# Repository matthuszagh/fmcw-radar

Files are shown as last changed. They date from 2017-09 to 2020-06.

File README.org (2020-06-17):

This repo has been moved to [[https://github.com/matthuszagh/fmcw][fmcw]] to support git-lfs (public forks do not support LFS).

* About
:PROPERTIES:
:ID:       20ff1c28-cfc6-4280-8501-83314fee390d
:END:
This repo includes the custom PCBs and PC control software necessary
to build and operate a 6GHz FMCW radar. It also includes a number of
other useful additions, such as RF and SPICE simulations (in progress)
as well as CAD designs for the horn antennas and PCB cases.

The project is a fork of [[https://github.com/Ttl/fmcw3][Henrik's excellent design]]. Although I've made
a number of [[id:8f78da8c-ec0c-40f3-9b8b-6c1af11f4bb2][significant changes]], most of the main PCB (as of this
writing) is still identical to Henrik's. Despite the fact that Henrik
deserves a large share of the credit for this project, he is in no way
affiliated with this fork.

This project is still in its early stages. In particular, there are a
number of hardware issues that make this version inferior to
Henrik's. These will be fixed in a future version, but I would hold
off building this version until these issues are fixed.

* TODO Capabilites
Briefly mention the radar's capabilities.

* TODO Installation
* TODO Additional hardware
* Modifications from the original
:PROPERTIES:
:ID:       8f78da8c-ec0c-40f3-9b8b-6c1af11f4bb2
:END:
The FPGA code has been completely rewritten and expanded so that
nearly all data processing is now done on the FPGA. This was done
while keeping the same FPGA chip. This allows the fully processed
output to be plotted in realtime and simplifies the data processing
requirements of the host PC code. The FPGA code also includes
automated tests and, in some cases, formal verification.

Because the FPGA responsibilities were expanded, the PC software had
new requirements and had to be rewritten as well. The software is
multithreaded and separates out the task of acquiring data from
plotting it. Additionally, the software and FPGA gateware have been
designed to make the radar easier to debug. For instance, data
processing can be shared in any way between the software and FPGA,
which makes gateware bugs easier to isolate. It's also possible to
request data from the FPGA in any intermediate form.

I completely redid the PCB layout because of the need for a new power
amplifier (note that this introduced at least [[id:0246fbe1-ba4a-4bf6-b551-a896264dea3a][one significant issue]]).

I've added horn antennas that can be built by anyone with access to a
3D printer. There's also a 3D-printable mount to hold the entire
structure.

I've greatly expanded the documentation, which should be useful to
anyone who wants to understand how the radar works in detail.

I've added a number of RF simulations (using [[https://openems.de/start/][OpenEMS]]) and spice
simulations (using [[http://ngspice.sourceforge.net/][Ngspice]]).

Finally, I have plans to multiplex 8 receiver antennas across the 2
receiver channels for better angular resolution. The PCB has already
been built (though is untested), but I haven't yet had the time to
write the FPGA code and software to support it.

* Issues and To-Do
:PROPERTIES:
:ID:       0246fbe1-ba4a-4bf6-b551-a896264dea3a
:END:
The power circuitry that was added to accommodate a new power
amplifier (the original was deprecated) adds noise that shows up in
the final output. Because of this problem, if you're able to track
down the old power amplifier I'd recommend using Henrik's design
instead. My FPGA code and software (at least for now) should be fully
compatible with the original hardware. I intend to fix this problem in
a future version.

I'm currently working on a number of RF simulations that will
eventually lead to a replacement of some of the RF PCB
layout. Currently, I have very limited information on whether these
parts of the PCB actually work the way they should. Areas of focus
include transmission line characteristic impedance, transmission line
to SMA transitions, and replacement of discrete components such as
couplers, attenuators, etc. with the equivalent components etched
directly onto the PCB. Once the RF simulations are complete, I'd like
to prototype these before actually building them into the
radar. Unfortunately, I don't yet have the proper testing equipment
for this (building a VNA is the next project...).

* Contributing
Pull requests and issues welcome. I'm open to suggestions for hardware
modification, although may or may not be able to merge those commits
depending on whether I can test the change.

* TODO Operation
Link blog post.

* TODO Attribution
+ Henrik, of course (see [[id:20ff1c28-cfc6-4280-8501-83314fee390d][About]]).
+ An additional thanks to AlexBdx for finding a way to 3D print horn
  antennas.

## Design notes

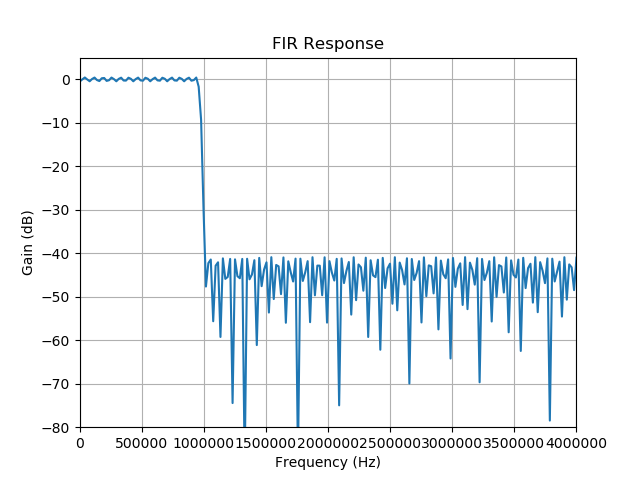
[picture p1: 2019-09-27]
fpga/fir/plot_response.png

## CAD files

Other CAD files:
hardware/cad/antenna-mount.scad
hardware/cad/horn-antenna.scad

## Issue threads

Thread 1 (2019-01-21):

USB type C

matthuszagh, 2019-01-21:
I'd like to use a USB type C connector in place of the current micro B USB 2.0 connection. The plugs/receptacles are symmetrical, support higher speeds (if the interface/FPGA will allow it) and are the future, so it would be nice to gain experience with them. The interface controller will need to be changed, since the FT2232H does not support USB standards past 2.0.

Ideally, I could use this to power the board. However, that would require at least 1 boost converter (an amplifier in the transmitter requires a 10V power supply) and might be a bit tight on current. USB C should allow up to 3A of current at 5V, which would be theoretically sufficient, but it doesn't leave a lot of leeway.

Closed 2020-06-03.

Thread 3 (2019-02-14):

Fix FT2232H EEPROM

matthuszagh, 2019-02-14:
Change 93LC46BT-I/SN to 93LC46BT-I/OT and add 10k pull-up resistors to EECLK and EECS (pull up to 3.3D).

Closed 2020-05-19.

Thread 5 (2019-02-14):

Change pushbutton switch type

matthuszagh, 2019-02-14:
Exchange the current switch (EVP-AWBD2A) with the one used in the icebreaker board (PTS810 SJM 250 SMTR LFS) which is a much better size and is generally nicer.

Closed 2020-01-03.

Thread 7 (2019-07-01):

Patch antenna

AlexBdx, 2019-07-01:
Hello,

Is this patch antenna the one that Henrik used or your own design based on his post?

matthuszagh, 2019-07-02:
It's basically Henrik's. He gave me the gerbers for an array of 2 but I turned it into a single patch and imported it into kicad (the one patch should be identical to his though). If you're interested in the original gerbers I can give those to you. I'll be turning this into an 8-array antenna (multiplexed through 2 rec channels) and running sims in openems, just fyi if you're interested. Not sure the eta on that

AlexBdx, 2019-07-02:
Yeah I saw your multiplexing board. I have ordered a copy of your array of 2 after talking with Henrik. What connectors did you use? I saw a footprint with 9 holes and was wondering of you had a reference for it.

matthuszagh, 2019-07-02:
Hm 9 holes.. Are you talking about the RF via (reference F1 and F2)? That one only has 6 holes though. If you provide me more info or a screenshot or something I can tell you what it is. For sma cables I'm using [these](https://www.amazon.com/gp/product/B072FS4WMK/ref=ppx_yo_dt_b_search_asin_title?ie=UTF8&psc=1). They work fine. you'll need a transmission antenna too. have you sorted that yet? I'm currently using [this one](https://www.amazon.com/gp/product/B07D28MW63/ref=ppx_yo_dt_b_search_asin_title?ie=UTF8&psc=1) planning to probably build my own later. If you want something cheap the one from the link is good. Unfortunately you lose half the transmission energy because the tx/rx polarizations don't match, but as a first pass to get the board working it's good

AlexBdx, 2019-07-02:
Yep I got that Tx. I saw that in your doc and that will be perfect for a first run (I saw a single feed version mentioned on Martin's website but could not find anyone that sold it).
Regarding the RX, I imported your files from the antenna folder and basically sent that straight to PCB manufacturing. In Kicad, everything appears as a via to me. Below is a the file I am using. Let me know if you can see it.
[Patch_2x5.zip](https://github.com/matthuszagh/fmcw-radar/files/3352443/Patch_2x5.zip)

matthuszagh, 2019-07-02:
ah i see why you're confused. that kicad_pcb file is wrong. fortunately the gerbers in the antenna directory look fine. in any event this is the [surface sma i used](https://www.digikey.com/product-detail/en/linx-technologies-inc/CONSMA001-SMD-G/CONSMA001-SMD-G-ND/4496569). That's all you need, plus the sma connector cables. i'm gonna try to track down the right kicad_pcb file but might not get to it right away.

AlexBdx, 2019-07-02:
Damn! I just uploaded all the files in Gerber (through KiCad) and then Saved As a kicad_pcb file. Did I have to make some modifications beforehand? I just got an email saying that the PCB had gone to the fabricator, but maybe I can cancel the order if the board cannot be easily modified. Let me know!
I'll order the SMA connector you mentioned so at least I have these ready.

matthuszagh, 2019-07-02:
Ah sorry about that! Yeah I'd try to cancel if you can, I think there's a good chance it won't work properly. To clarify, the exposed copper looks like a bunch of overlapping circles?

matthuszagh, 2019-07-02:
For reference the correct gerber looks like this
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

AlexBdx, 2019-07-03:
Okay, can you send me the correct files you have? Or maybe update the repo? It might be easier to swap the gerber files at the fabricator than outright cancel as my order is grouped with dozens of others on a panel.

matthuszagh, 2019-07-03:
The gerbers in the repo are right but it looks like kicad doesn't know how to convert it to a kicad_pcb file. I just tried the conversion here. does the mfg allow you to just send gerbers? i'd just use those directly

AlexBdx, 2019-07-03:
Wow yes indeed! I tried to upload the gerber zip that you have in the antenna folder and it looks much better. The attached shape is correct right?
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

matthuszagh, 2019-07-03:
Looks good!

AlexBdx, 2019-07-11:
Hey,
I put together the antenna and wired everything, but unfortunately I'm not getting any meaningful data yet. The ADL5802 on the board gets really hot and it seems that the LOIN/LOIP pins are shorted, even if I cannot see any soldering issues on the board. Did you have troubles with this chip at all?

matthuszagh, 2019-07-12:
Not really, the only issues I encountered were a few simple shorts that we are all fixable. The trick was tracking them down.

AlexBdx, 2019-07-13:
Mmmh, I'm a little puzzled. I get some data, but it looks like crap. My channel 2 does not seem to be getting anything meaningful.
Do you have a log file you could share so I can run plot_log and see how the results should look like when it works?
I uploaded one of mine here if you are interested/have time to look at it: [https://github.com/AlexBdx/fmcw3/tree/master/pc/python2/run_away](run_away)
The log file is called run_away.log and in the img/ folder you have the plots I generated - they don't look so good. Let me know!

matthuszagh, 2019-07-19:
https://www.dropbox.com/s/luuqggbdlmfhpul/fmcw.log?dl=0

here's a log i took. you can't really see anything on the angular range plots, but the range time plot is ok. i'm hoping the antenna simulations and multiplexed antenna will yield something with better angular resolution and better snr, but not done with that yet.

I took a look at yours and it seems like you're getting repeating data.. not entirely sure what might be causing that. did you check for shorts at the receiver? I had one on one of the lna's that caused bad data. just a thought.

AlexBdx, 2019-07-19:
in read_settings, it raises a ValueError due to missing error.
if header != 'fmcw3;':
        raise ValueError('Missing header')
Did you modify fmcw3.py and discarded the header?

I have fixed "some" issues on my board (found one tricky short on a non-populated yet connected pad) but I'm done 100% done. I hope to find the others soon.

matthuszagh, 2019-07-19:
oh yeah i changed the name. you have to modify the python code to look for fmcw, not fmcw3

AlexBdx, 2019-07-20:
Do you have the corresponding plot_log.py file too?
I've tried yours & Henrik's legacy file, removing errors one after another until I would be processing the reading the whole log... only to end up with empty arrays.
Maybe you could send me the one you used so I don't have to reinvent the wheel on this one.
Have a great weekend!

matthuszagh, 2019-07-24:
https://www.dropbox.com/s/3eo8sn8id342ecr/plot_log.py?dl=0

let me know if that works

AlexBdx, 2019-07-24:
Stupid mistake on my end: I was trying to read your file with python 2 (what Henrik initially used) while I had to run it with python 3. Your range-time plot is noisy, but I can definitely see a signal on it!! Looks great!
Yes, it did work. A couple of questions:
- I thought that the IF time domain waveforms would be limited to [-1; 1] V but I see that the signal spiked outside these bounds at times. How is that happening? I thought the ADC's largest sampling range was 2V.
- The IF time domain plots have a ton of noise in your signals. Is that normal? How can the noise be reduced?
- Each channel on each sample of the IF time domain plot seems to have a mean of about -0.25 V. Why isn't it 0 V?

AlexBdx, 2019-07-29:
I forgot to add one of the pictures I had processes to illustrate my previous message. Let me know when you have a second to look at it. Thanks!

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

AlexBdx, 2019-07-31:
Wow I finally fixed it. I found a new issue after checking everything again, and now it works. Check that out:

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

matthuszagh, 2019-07-31:
glad you figured it out!

Closed 2019-07-31.

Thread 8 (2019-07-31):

Multiplexed fmcw

AlexBdx, 2019-07-31:
Time to get real, now that the board is working.
How far did you get on the multiplexing? I saw your Kicad file, did you:
- Make it?
- Write the code FPGA code to support it?
- Python/pc code for it?
I'm interested in pushing a little forward that idea, so let me know!

AlexBdx, 2019-08-30:
Regarding point 3, I've made some progress actually.
Would you mind testing my version of the fmcw3 python code and let me know if it works on your end too?
You would need to install the files I used with `pip install fmcw` and then run the attached main file. Thanks!
[rt_fmcw3.zip](https://github.com/matthuszagh/fmcw-radar/files/3558005/rt_fmcw3.zip)

matthuszagh, 2019-09-03:
I'll try to test this when I can. What's the purpose of this code? Is it to support antenna multiplexing? If so, my testing will be a bit delayed since I don't yet have the receiver antennas and haven't modified the FPGA code to support it.

One of the main goals of this project for me was to learn FPGA dev, so I've been working to get all functionality (except plotting of course) onto the FPGA. All the individual modules work and now I just need to connect them together and test it, so hopefully I'll have a complete solution (including realtime plotting and antenna multiplexing) soon. I'll post back when I do.

AlexBdx, 2019-09-03:
In a nutshell:
- Work at a higher level than Henrik's code by providing functions/classes/modules... and documenting stuff a lot more
- Add some features

Key features:
- Runs Henrik's core physics
- Display IF signals/Angle/Range time in real time. Optionally, connects to a webcam and records video of the scene imaged.
- Saves data to binary & csv (in csv mode you save the integer values of the IF signal)
- Way more robust management of the USB connection, less than 5% of the sweeps are dropped now.
- Heavy reliance on the multiprocessing library to allow regular laptop to perform okay

AlexBdx, 2019-09-03:
I know ~ nothing about FPGA, so I'm glad you are taking a stab at this challenge. Performing the FFT on the FPGA would definitely be more efficient than on a laptop. However, it's a lot harder to write than a few call to Numpy so if you go that route I would be interested to see how you did it.

matthuszagh, 2019-09-03:
Nice job getting all this working with just python code. I'm looking forward to testing it. I actually think your solution makes more sense for most applications than mine. The FPGA code is more efficient, but less flexible when you want to change something and as you mentioned harder to program. I'll be happy to walk you through it when I'm sure it actually works.

AlexBdx, 2019-09-03:
Thanks! Let me know if my script works for you. If you use windows, there might be some linux specific implementations that derail it.
Also I added my personal script to the fmcw library so you can just run YYMMDD_rt_fmcw3.py from there and see what happens. Thanks!

AlexBdx, 2019-09-14:
I've created a slack channel for the fmcw so we stop writing endless issue threads
[https://join.slack.com/t/fmcwworkspace/shared_invite/enQtNzYyNTcwNDI0MTgyLTU4NzEzMDA3NTU5ZjI2YTY3MTI5ZmQ0ZDFkOGNlNGRjMzgxNzE1NWZhYjgxZDIyNDlkM2U3YjRhY2RhMGNlOTg](url)
Feel free to join!

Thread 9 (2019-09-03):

Homemade horn antenna

AlexBdx, 2019-09-03:
I remember you previously said you wanted to make your own antenna.
I found this article: https://antennatestlab.com/3dprinting
and made my own horn antennas for the fmcw3. They cost nothing and are fun to build.

AlexBdx, 2019-09-03:
Purely informational. If you do not have a 3d printer available you can email me.

matthuszagh, 2019-09-03:
This is awesome, thank you for sharing!

matthuszagh, 2019-09-03:
I'm curious, did you build small horn antennas for reception too, or just a large one for transmission?

AlexBdx, 2019-09-03:
If I just want the range-time plot, I use two horns like Henrik does (check out his new article if you have not already).
If I want the angle plots, just for the transmission due to the need to have a specific alignment between the antennas.
That being said, you could probably design a very narrow horn, and stack them side by side with a lambda/2 pitch. The horn would be non-ideal, but it might be better than the FR4 patch \o/

matthuszagh, 2019-09-03:
Yeah I'm not in love with the patches. The bandwidth on them is terrible and FR4 is tough to work with for antennas. I'll see if I can make horns small enough for reception and report back if they work any better.

AlexBdx, 2019-09-03:
Sounds good.

matthuszagh, 2019-09-04:
you used the wr187? what did you do for waveguide coax adapters?

matthuszagh, 2019-09-04:
wr159 is a better frequency range but i don't see an stl model for it

AlexBdx, 2019-09-04:
No I made a WR-159

matthuszagh, 2019-09-04:
is the model there and i missed it or you made it yourself?

AlexBdx, 2019-09-04:
I made a CAD myself for the WR-159 and 3d printed it. I used the following drawing: https://www.pasternack.com/images/ProductPDF/PE9860-15.pdf
My 3D printer can only do 6"x6"x6" so I had to split it in 2. I did not have the motivation to split it in 4 to make a 20 dBi version

AlexBdx, 2019-09-04:
Let me see if I can 1) find the file 2) attach it on Github

AlexBdx, 2019-09-04:
>
>
> you used the wr187? what did you do for waveguide coax adapters?

2nd part of the answer: I *could* have 3D printed one, but I concluded it would be too risky. So I just bought this: https://www.ebay.com/itm/232688038314

matthuszagh, 2019-09-04:
makes sense, thanks

AlexBdx, 2019-09-04:
[WR-159_15_dBi.zip](https://github.com/matthuszagh/fmcw-radar/files/3572572/WR-159_15_dBi.zip)
Assembly_15_dBi is for reference: there are two parts due to the size constraints of my printer. Support_PLA is a conical section that holds the top and bottom parts aligned while you weld the two parts together (via solvent or glue or else)

matthuszagh, 2019-09-04:
thanks!

Closed 2019-09-03.

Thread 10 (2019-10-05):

Power amplifier is turned on when power is supplied

matthuszagh, 2019-10-05:
The power amplifier is enabled with a low voltage. Perhaps this should
be inverted.

matthuszagh, 2020-06-03:
This isn't a problem. Since the FPGA IO pins are high-Z before configuration, the PA will be disabled by default. However, since the FPGA is configured to read its bitstream (master SPI) from the onboard eeprom (w25q32), ensure this doesn't set the pa_en_n_o pin to 0, in which case the PA will be on soon after power is supplied.

Closed 2020-06-03.

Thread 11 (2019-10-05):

ADC references are not connected to 3V power rails

matthuszagh, 2019-10-05:

matthuszagh, 2020-01-03:
Fixed: https://github.com/matthuszagh/fmcw-radar/commit/e4269df8504eb95caaa8f14ce68d8890eff62e64

Closed 2020-01-03.

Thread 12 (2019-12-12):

500KHz tone in output

matthuszagh, 2019-12-12:
I think this is coming from the power supply (the upstream switching
converter switches at 500KHz).

The first step is to measure the power supply noise and determine if
that is indeed the source of the noise. If so, the contents below
apply. If not, I don't yet have an alternate theory.

The tone comes from the TPS5420D switching converter. The problem
is some combination of the following:

1. TPS5420D produces too much ripple. Could use the old L7980 instead.
2. TPS7A7001 linear regulator (downstream) has inadequate PSRR. In
   this case, it should be replaced with the old TPS7A91 (we'll need
   2, 1 for the mixer and another for the power amp, in order to meet
   max current draw).

Possible solutions (some combination of these):

1. Revert to L7980 and TPS7A91. Have mixer and power amp use separate
   TPS7A91 to accommodate current draw.
2. Use a capacitance multiplier (see the art of electronics section
   8.15.1) between the converter and regulator.

matthuszagh, 2020-06-03:
New design reverts to L7980.

Closed 2020-06-03.

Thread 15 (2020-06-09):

FPGA mode pins should be switchable

matthuszagh, 2020-06-09:
Should use a switch on the FPGA backside to allow the mode pins to be set without soldering/desoldering resistors. This is useful, for instance, if you don't want the FPGA to be automatically configured from SPI flash at startup.

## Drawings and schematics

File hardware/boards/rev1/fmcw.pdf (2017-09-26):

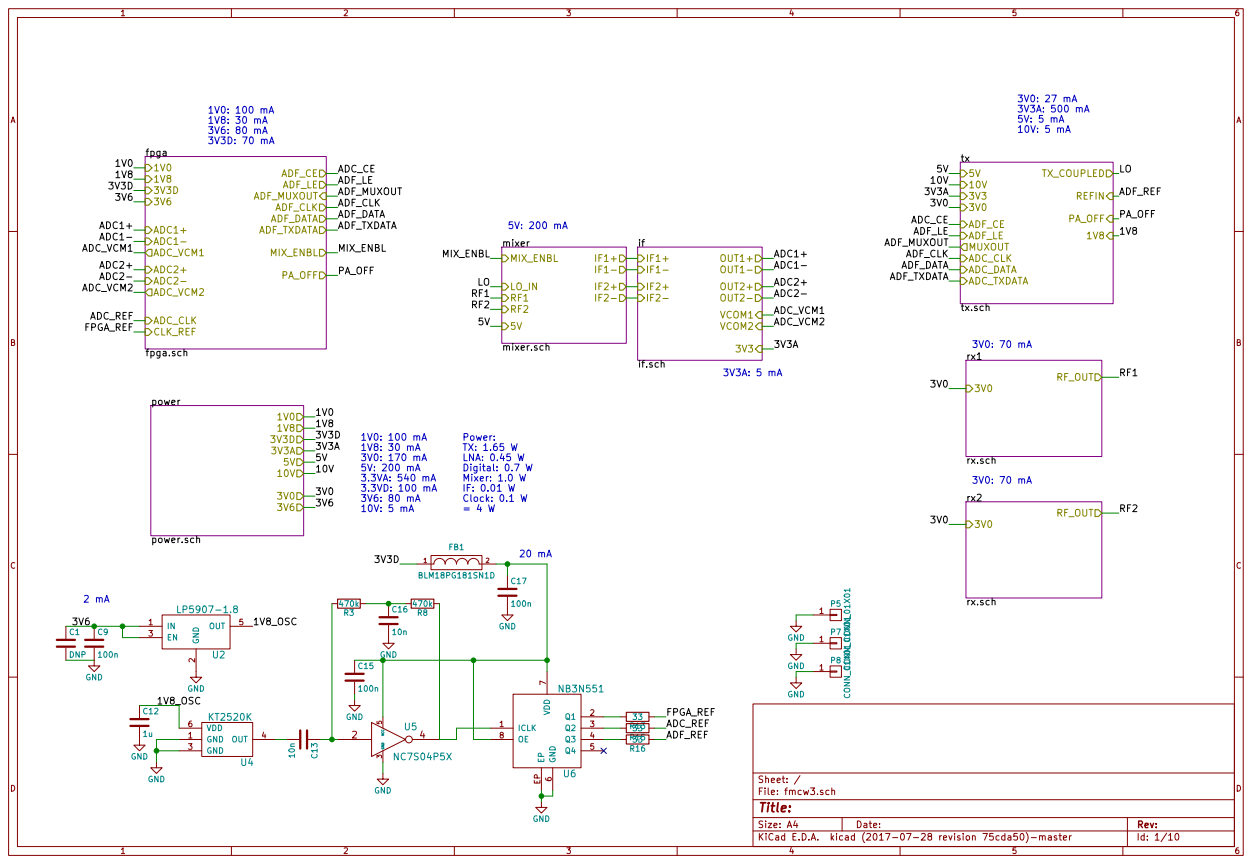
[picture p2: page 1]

Id: 1/10 Title: File: fmcw3.sch Sheet: /

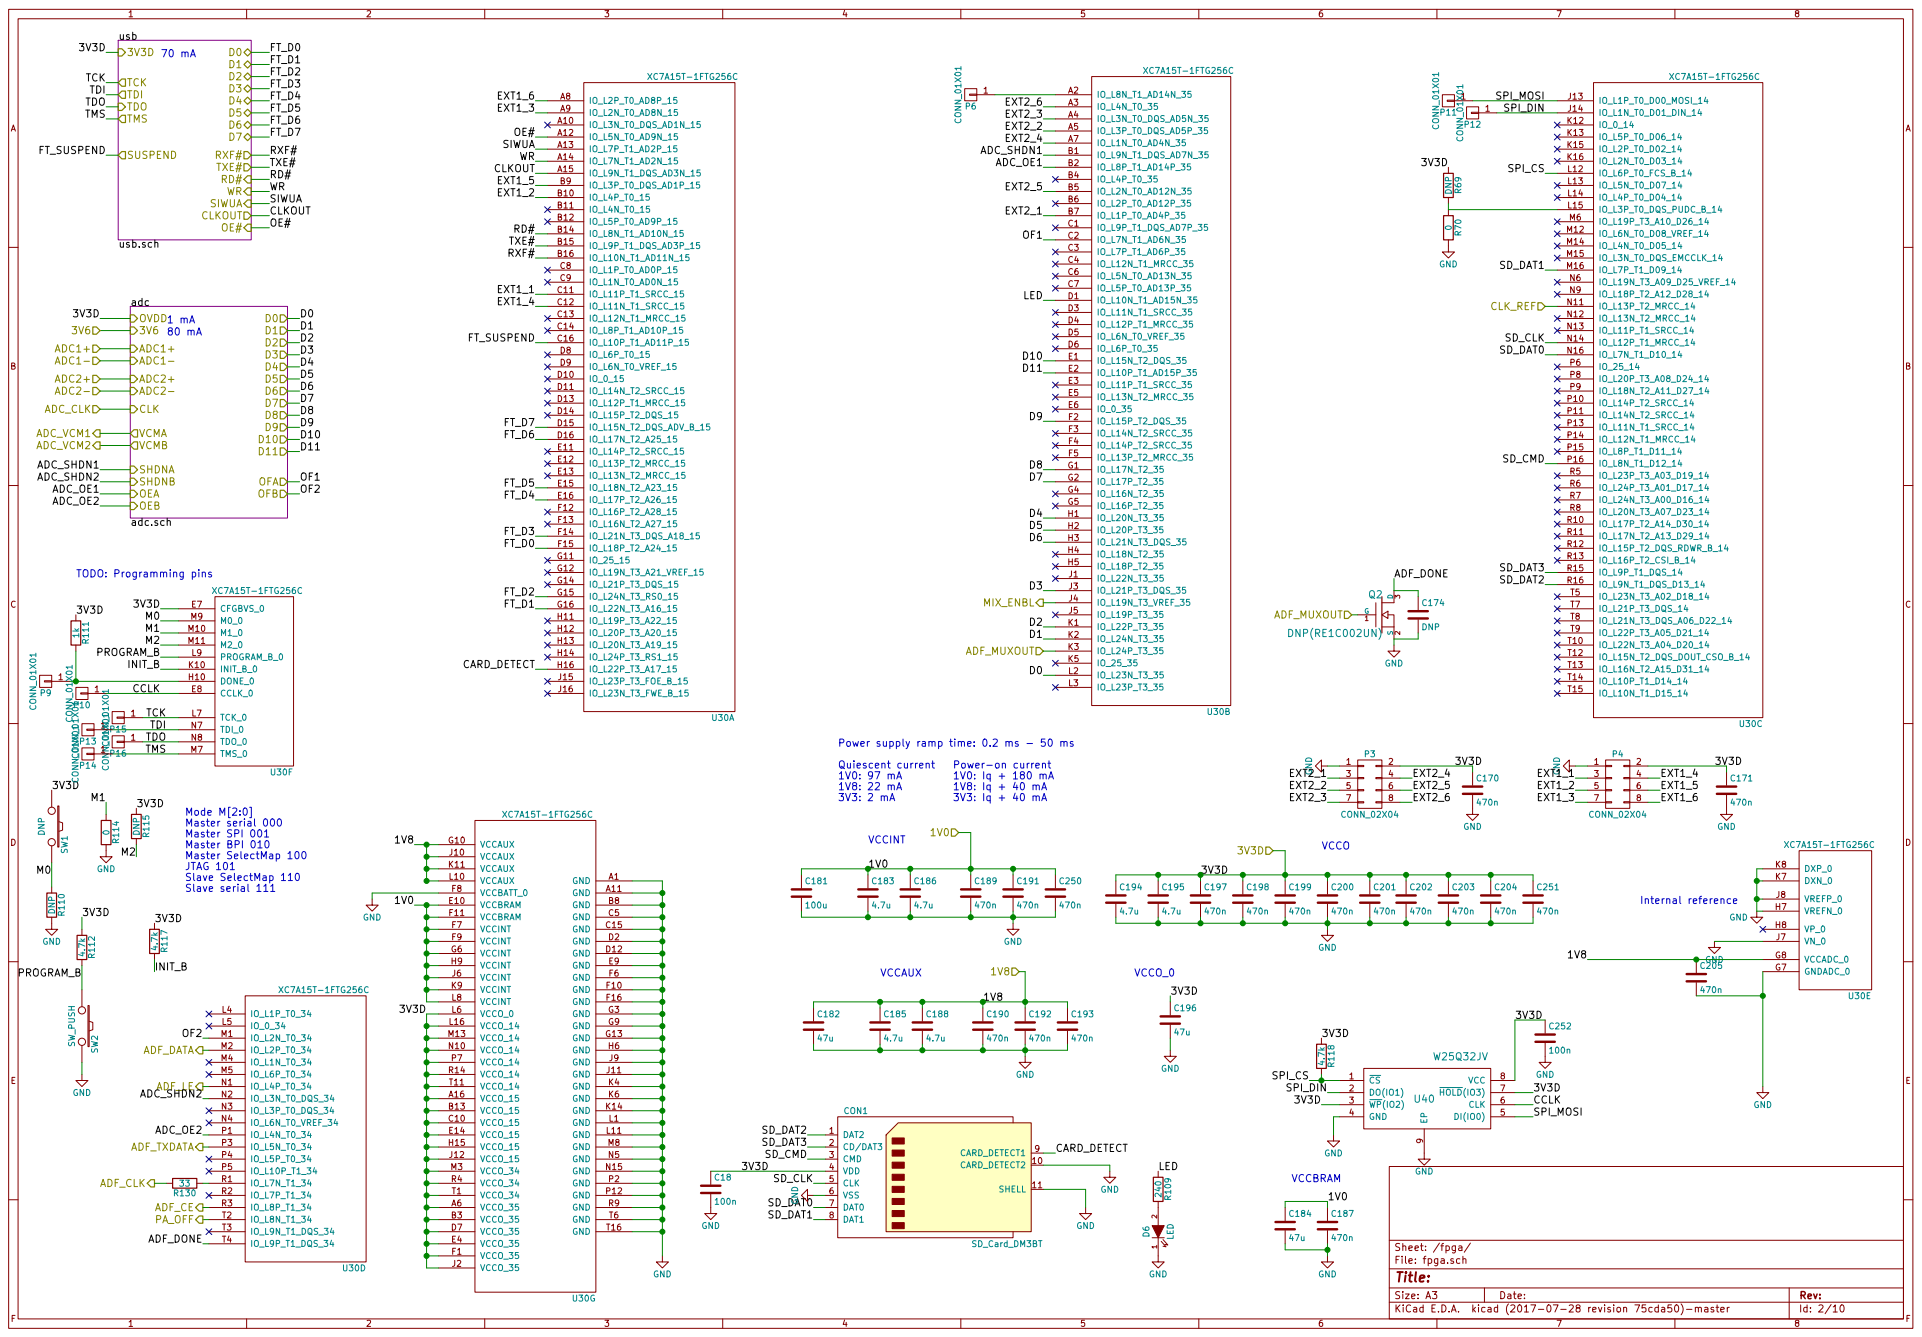
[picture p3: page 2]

SIWUA CLKOUT OE# SUSPEND

Power supply ramp time: 0.2 ms - 50 ms
Internal reference Quiescent current 1V0: 97 mA

Power-on current 1V0: Iq + 180 mA

Id: 2/10 Title: File: fpga.sch Sheet: /fpga/

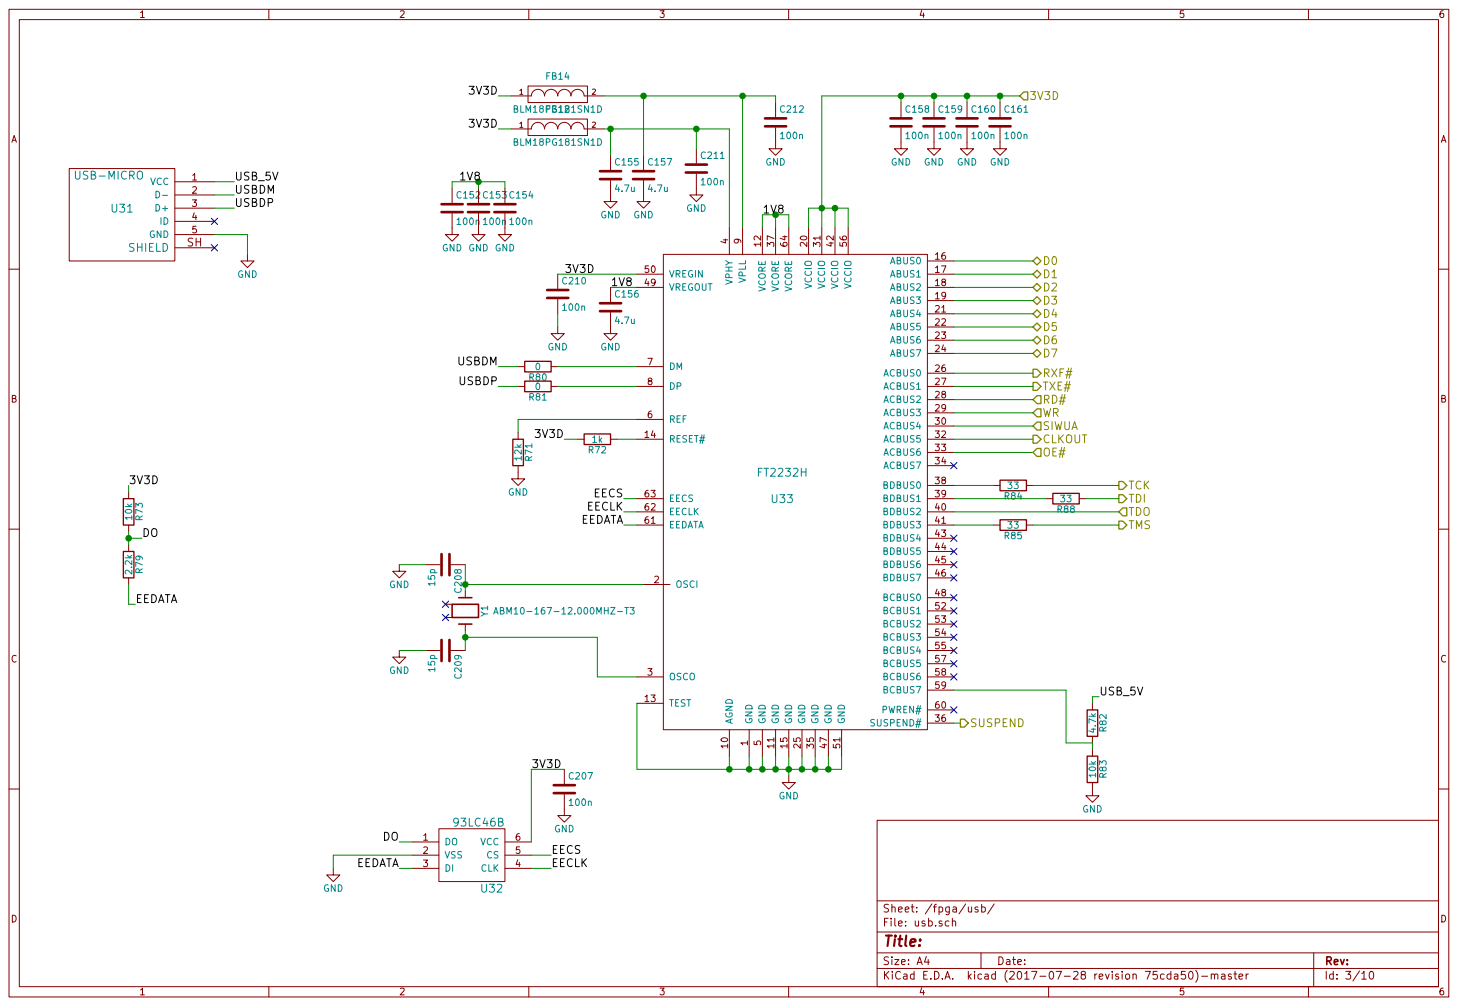
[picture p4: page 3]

Id: 3/10 Title: File: usb.sch Sheet: /fpga/usb/

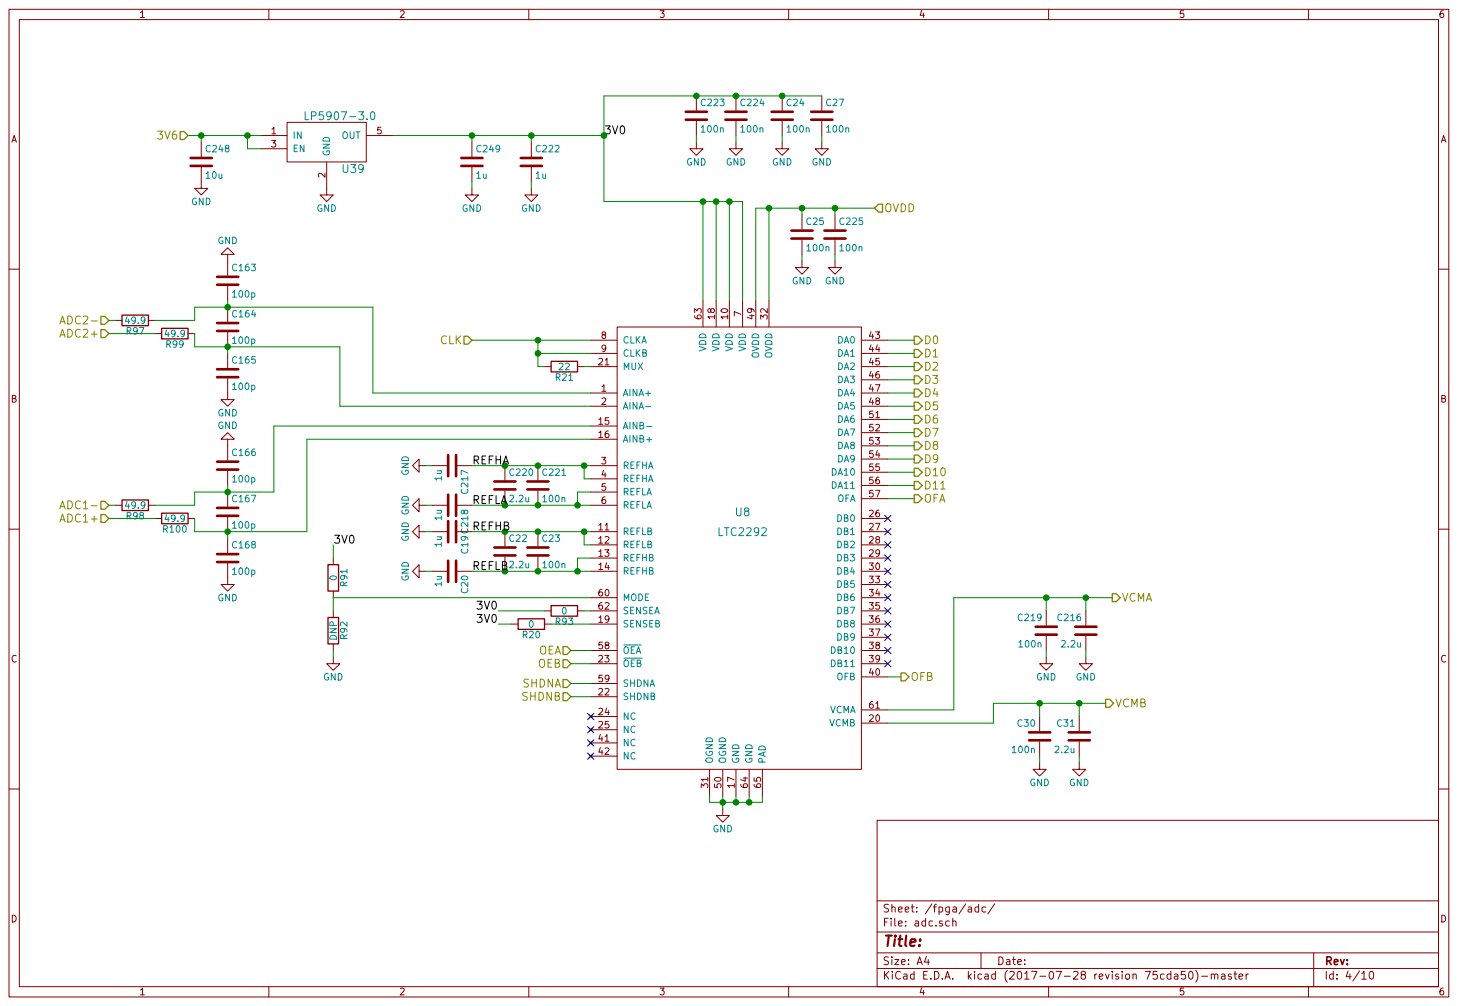
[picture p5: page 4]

7 CLKA 8 CLKB 9 VDD 10 VCMB 20 DB4 30 OFB 40 OGND 50 MODE 60 REFLB 11 MUX 21 OGND 31 NC 41 DA6 51 VCMA 61 REFLB 12 SHDNB 22 OVDD 32 NC 42 DA7 52 SENSEA 62 REFHB 13 OEB 23 DB5 33 DA0 43 DA8 53 VDD 63 REFHB 14 NC 24 DB6 34 DA1 44 DA9 54 GND 64 AINB- 15 NC 25 DB7 35 DA2 45 DA10 55 PAD 65 AINB+ 16 DB0 26 DB8 36 DA3 46 DA11 56 GND 17 DB1 27 DB9 37 DA4 47 OFA 57 VDD 18 DB2 28 DB10 38 DA5 48 OEA 58 SENSEB 19 DB3 29 DB11 39 OVDD 49 SHDNA 59 U8

Id: 4/10 Title: File: adc.sch Sheet: /fpga/adc/

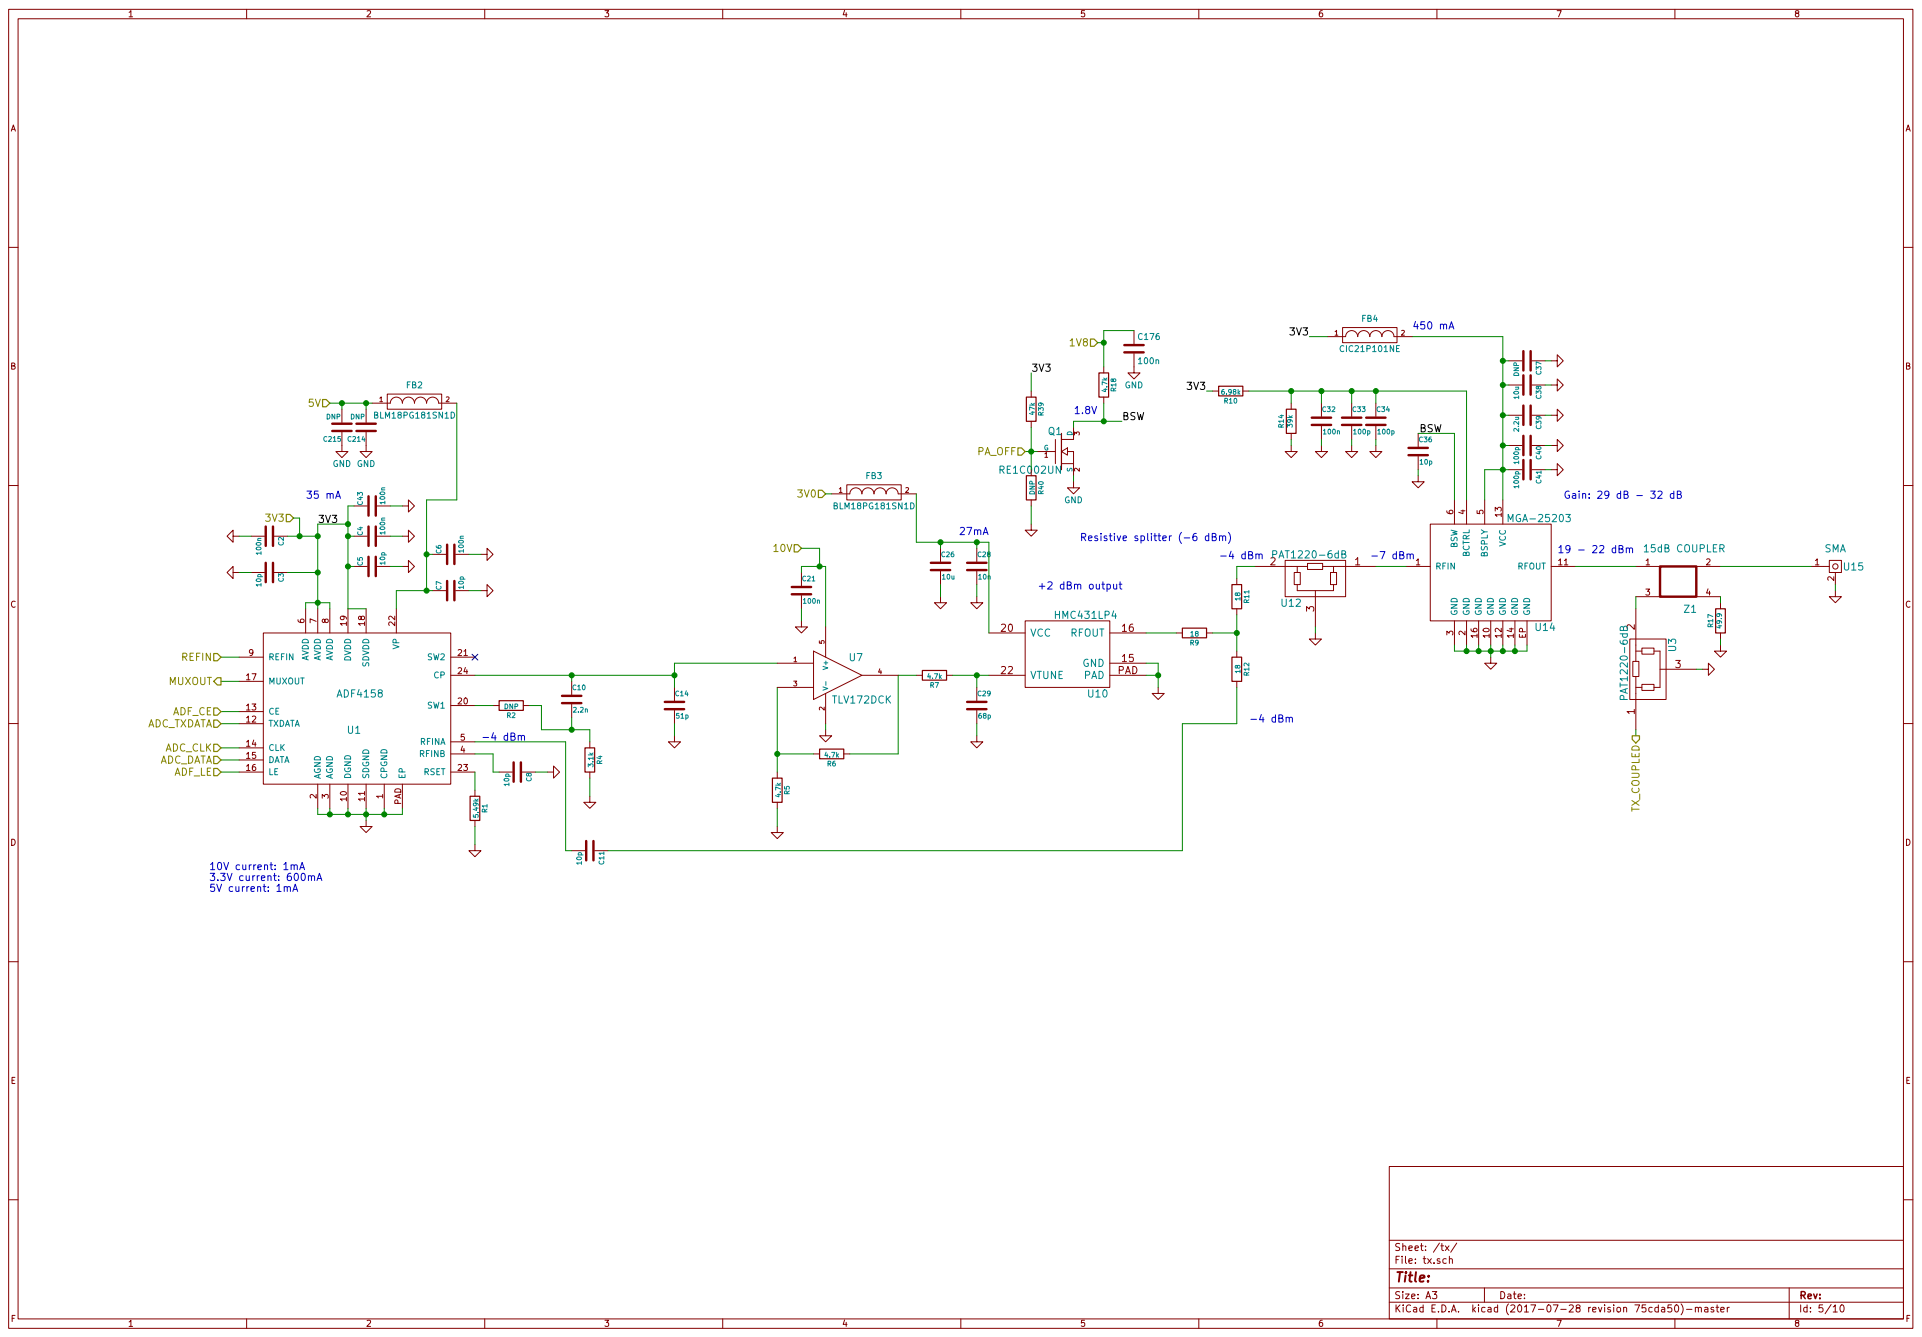
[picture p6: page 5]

6 GND 10 RFOUT 11 GND 12 VCC 13 GND 14 GND 16 GND EPU14 MGA-25203 C40 100p C39 2.2u 10u C38 DNP C37 C33

8 REFIN 9 DGND 10 SW1 20 SDGND 11 SW2 21 TXDATA 12 VP 22 CE 13 RSET 23 CLK 14 CP 24 DATA 15

Id: 5/10 Title: File: tx.sch Sheet: /tx/

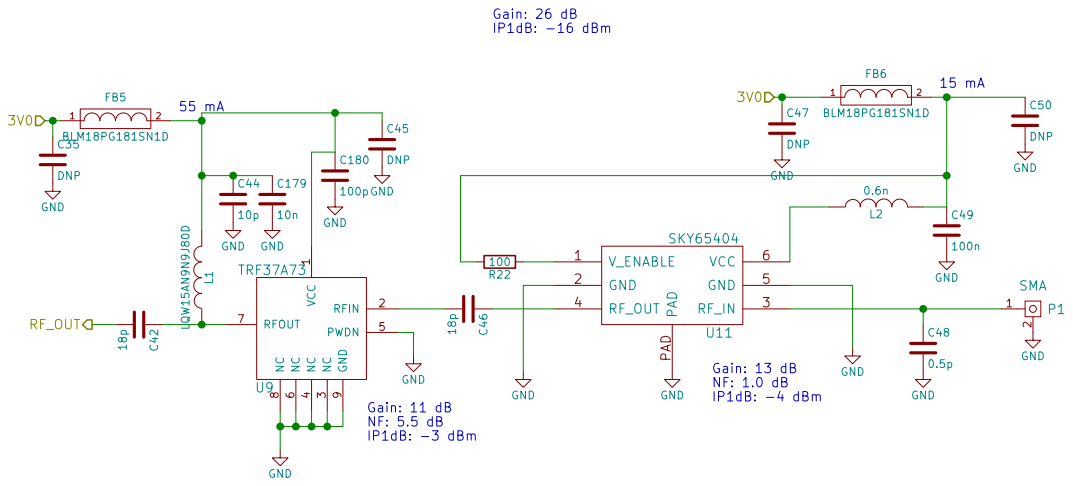
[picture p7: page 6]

IP1dB: -16 dBm
C47 DNP GND Gain: 13 dB NF: 1.0 dB

Gain: 11 dB NF: 5.5 dB

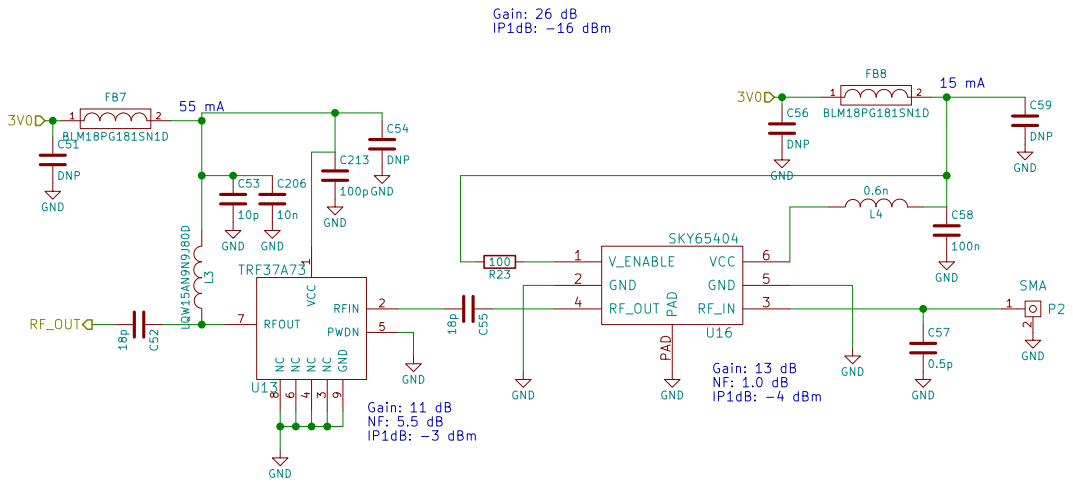
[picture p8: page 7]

IP1dB: -16 dBm
C56 DNP GND Gain: 13 dB NF: 1.0 dB

Gain: 11 dB NF: 5.5 dB

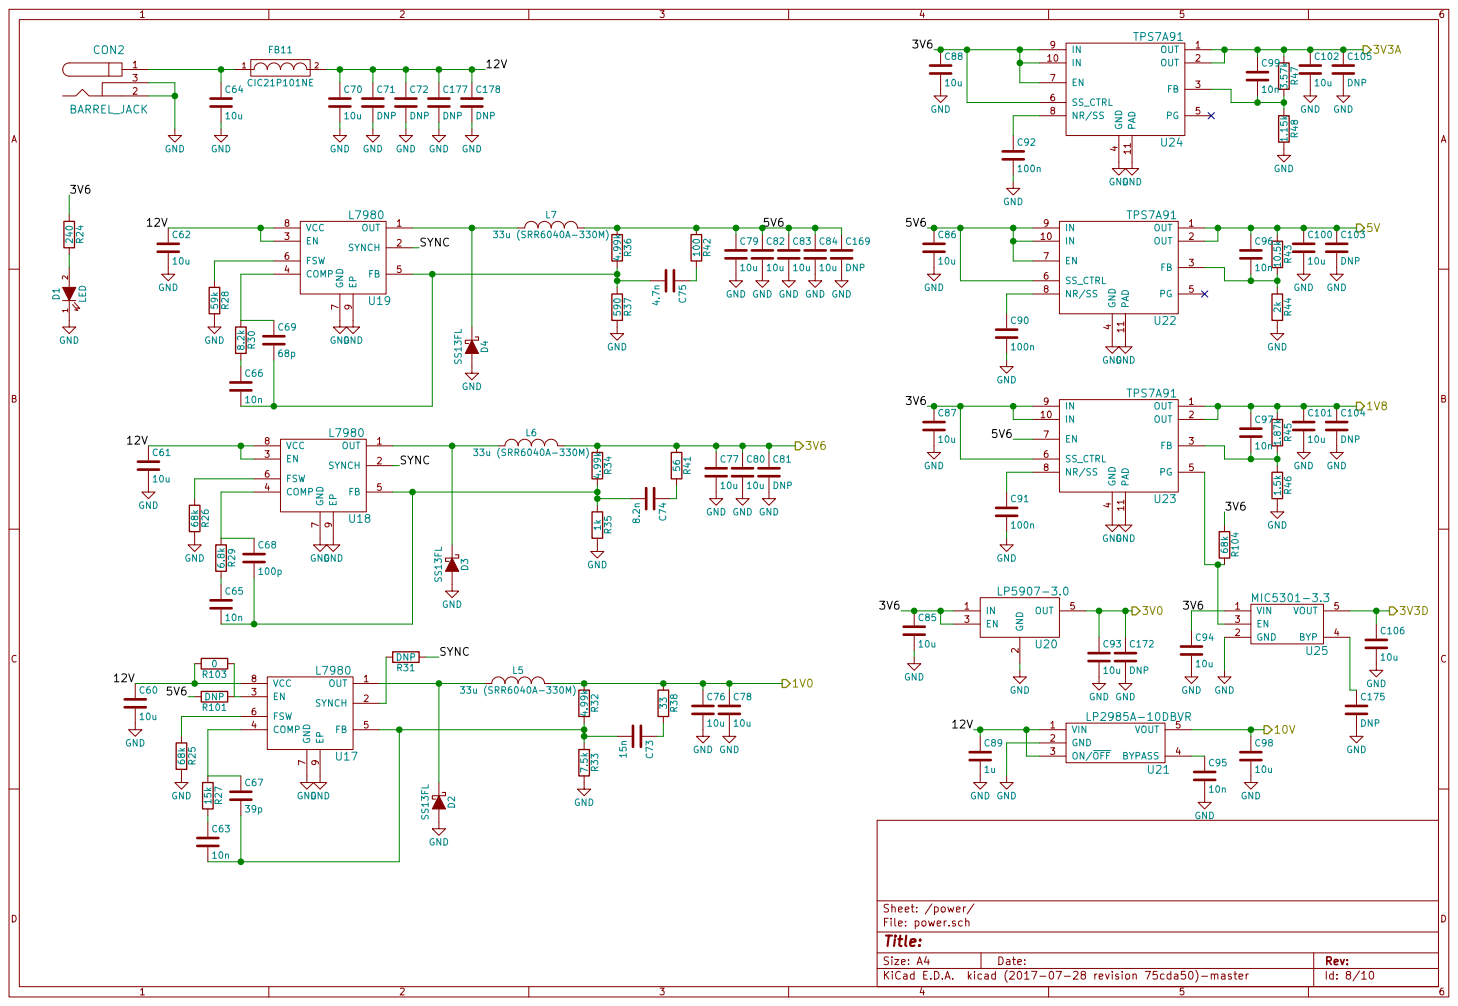
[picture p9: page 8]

4 PG 5 SS_CTRL 6 EN 7 NR/SS 8

1 2 D1 LED GND240 R24 3V6 OUT 1 SYNCH EN 2

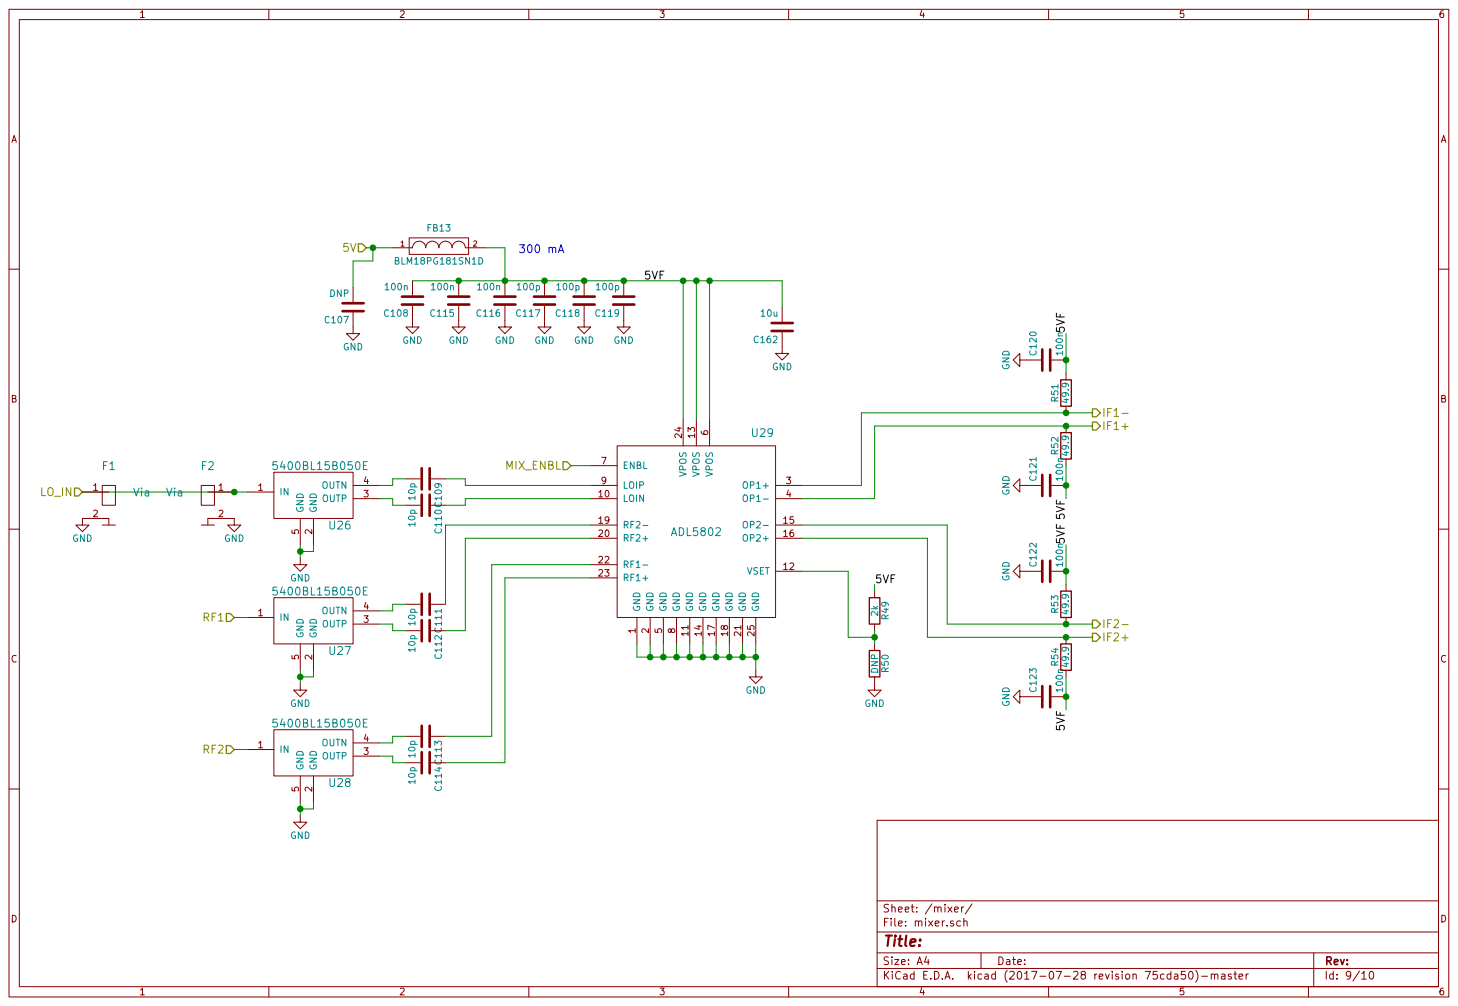
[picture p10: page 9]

Id: 9/10 Title: File: mixer.sch Sheet: /mixer/ GND

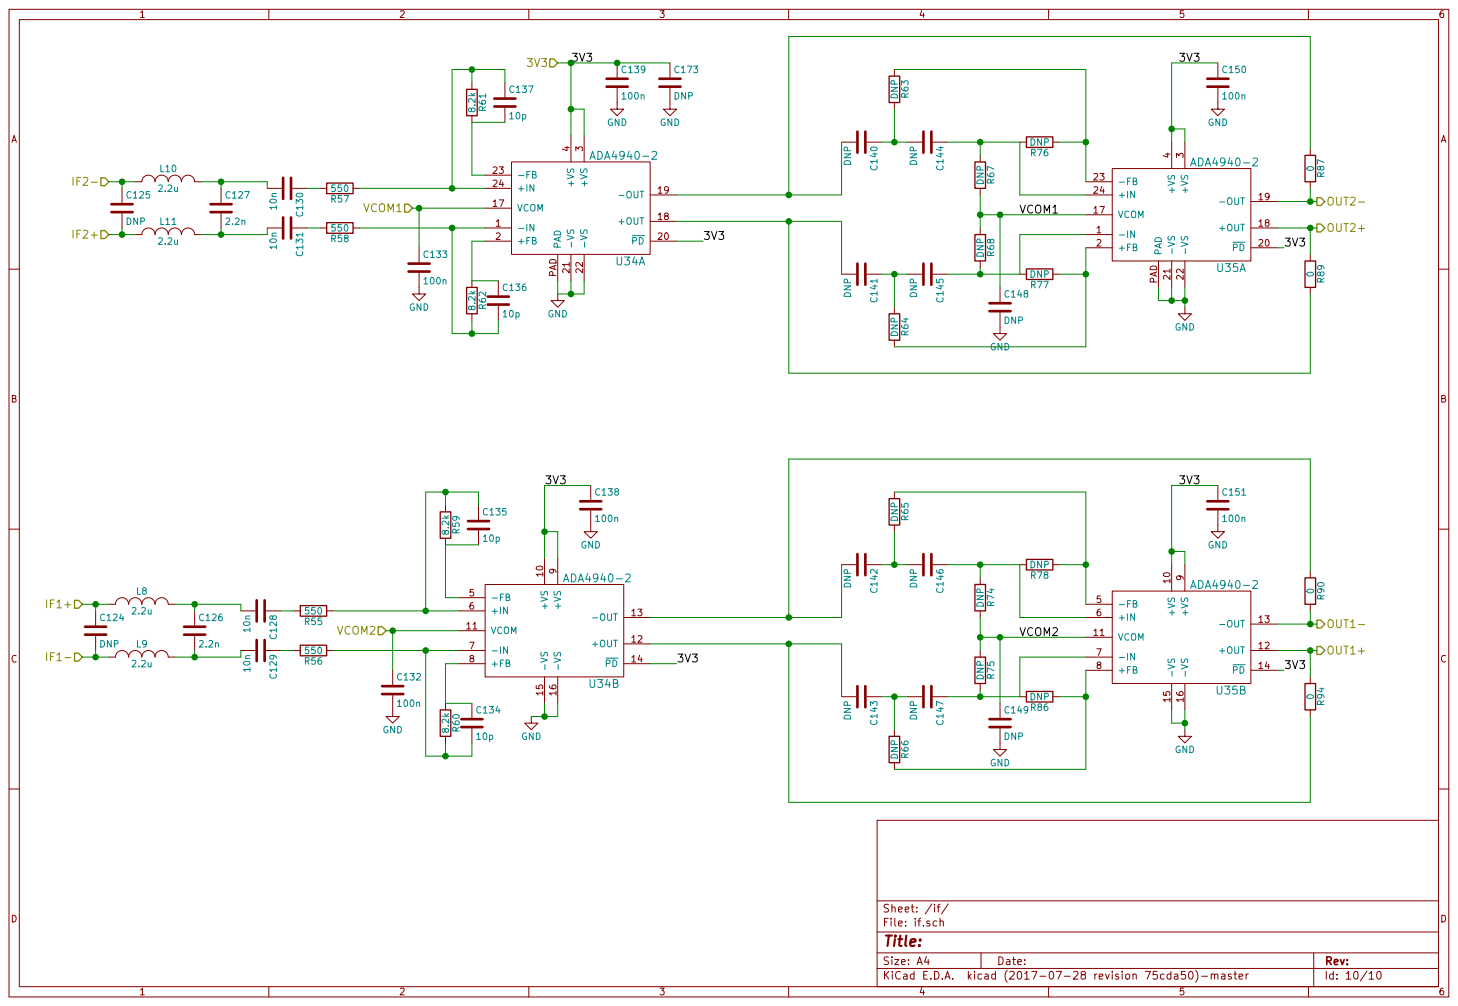
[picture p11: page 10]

Id: 10/10 Title: File: if.sch Sheet: /if/

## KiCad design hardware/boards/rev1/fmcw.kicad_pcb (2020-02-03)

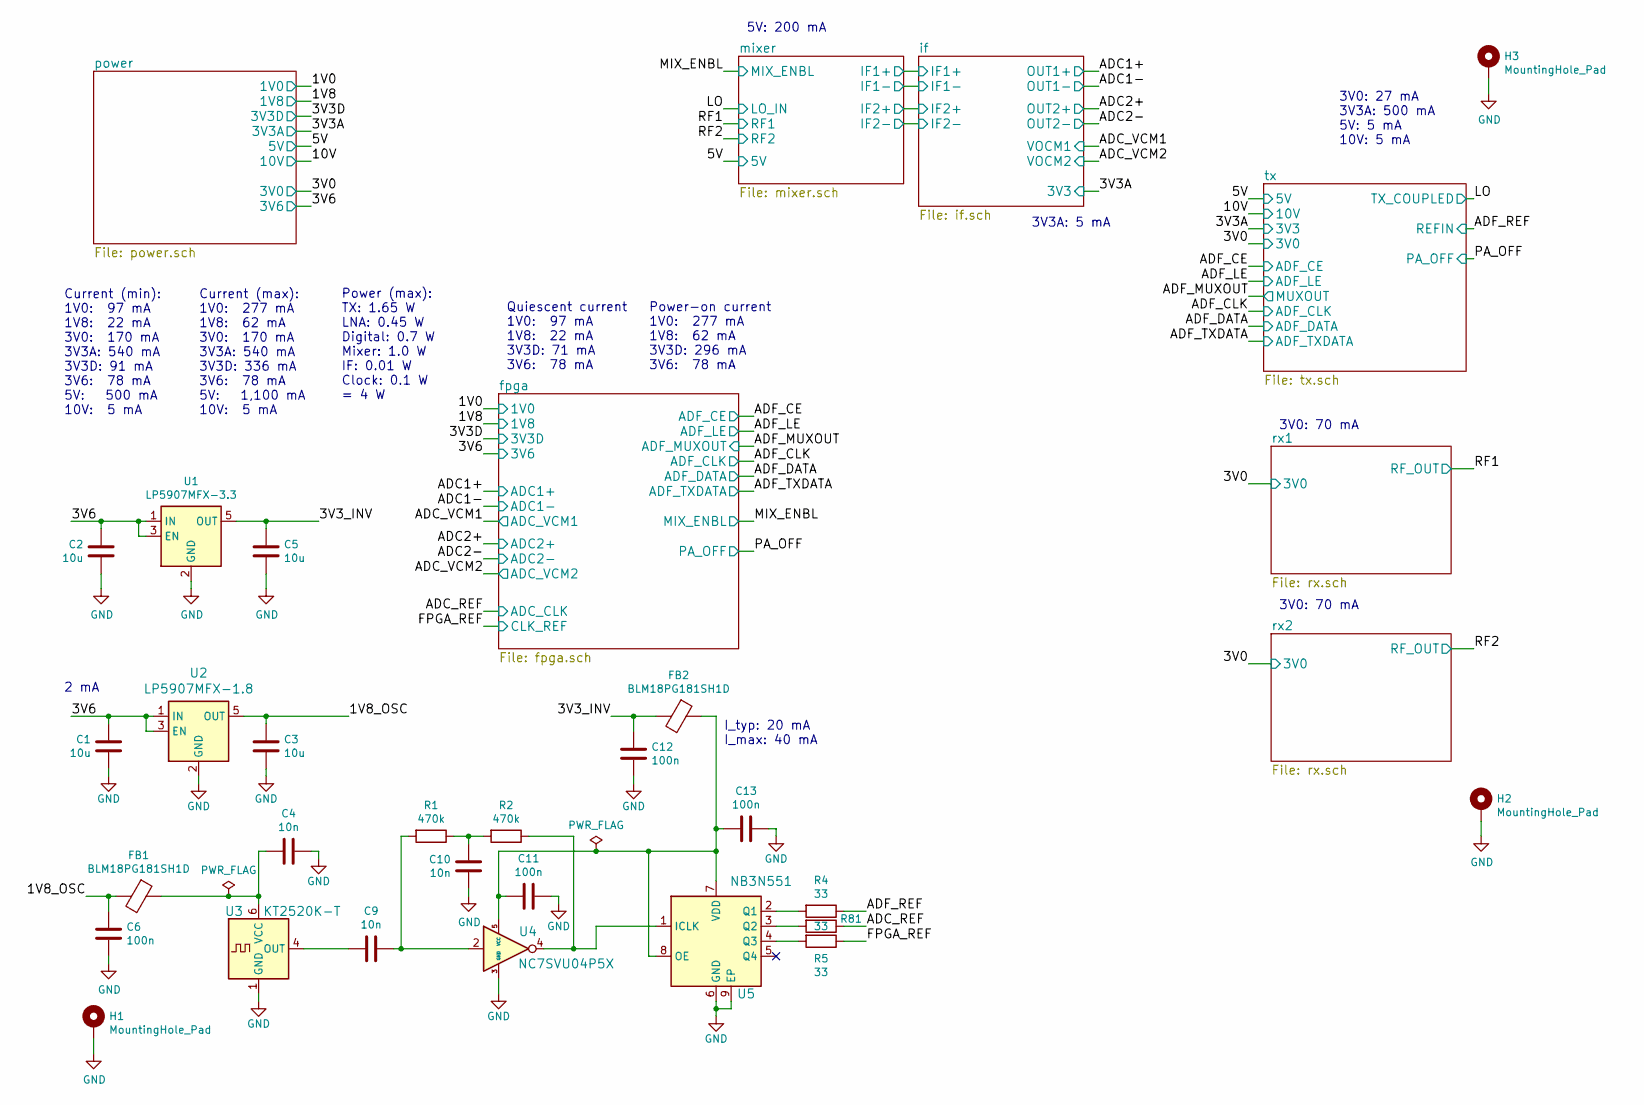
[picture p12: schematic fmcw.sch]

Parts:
C1, C2, C3, C5: 10u; C_0805_2012Metric
C4, C9, C10: 10n; C_0402_1005Metric
C6, C11, C12, C13: 100n; C_0402_1005Metric
FB1, FB2: BLM18PG181SH1D; L_0603_1608Metric
H1, H2, H3: MountingHole_Pad; MountingHole_3.2mm_M3_Pad_Via
R1, R2: 470k; R_0402_1005Metric
R4, R5, R81: 33; R_0402_1005Metric
U1: LP5907MFX-3.3; SOT-23-5
U2: LP5907MFX-1.8; SOT-23-5
U3: KT2520K-T; Oscillator_SMD_Kyocera_2520-6Pin_2.5x2.0mm
U4: NC7SVU04P5X; SOT-353_SC-70-5
U5: NB3N551; DFN-8-1EP_2x2mm_P0.5mm_EP0.8x1.2mm

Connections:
/1V8_OSC: C3.1, C6.1, FB1.2, U2.5 (OUT)
/3V3_INV: C5.1, C12.1, FB2.2, U1.5 (OUT)
/3V6: C1.1, C2.1, U1.1 (IN), U1.3 (EN), U2.1 (IN), U2.3 (EN); also elsewhere on the board
/ADC_REF: R81.1; also elsewhere on the board
/ADF_REF: R4.1; also elsewhere on the board
/FPGA_REF: R5.1; also elsewhere on the board
GND: C1.2, C2.2, C3.2, C4.1, C5.2, C6.2, C10.1, C11.1, C12.2, C13.1, H1.1, H2.1, H3.1, U1.2 (GND), U2.2 (GND), U3.1 (GND), U3.3 (GND), U4.3 (GND), U5.6 (GND), U5.9 (EP); also elsewhere on the board
unnamed: C4.2, FB1.1, U3.6 (VCC)
unnamed: C9.1, R1.2, U4.2
unnamed: C9.2, U3.4 (OUT)
unnamed: C10.2, R1.1, R2.2
unnamed: C11.2, C13.2, FB2.1, U4.5 (VCC), U5.7 (VDD), U5.8 (OE)
unnamed: R2.1, U4.4, U5.1 (ICLK)
unnamed: R4.2, U5.2 (Q1)
unnamed: R5.2, U5.4 (Q3)
unnamed: R81.2, U5.3 (Q2)

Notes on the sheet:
5V: 200 mA
3V0: 70 mA
2 mA
Current (max): 1V0: 277 mA 1V8: 62 mA 3V0: 170 mA 3V3A: 540 mA 3V3D: 336 mA 3V6: 78 mA 5V: 1,100 mA 10V: 5 mA
3V0: 27 mA 3V3A: 500 mA 5V: 5 mA 10V: 5 mA
3V3A: 5 mA
I_typ: 20 mA I_max: 40 mA
Power (max): TX: 1.65 W LNA: 0.45 W Digital: 0.7 W Mixer: 1.0 W IF: 0.01 W Clock: 0.1 W = 4 W
Quiescent current 1V0: 97 mA 1V8: 22 mA 3V3D: 71 mA 3V6: 78 mA
Power-on current 1V0: 277 mA 1V8: 62 mA 3V3D: 296 mA 3V6: 78 mA
Current (min): 1V0: 97 mA 1V8: 22 mA 3V0: 170 mA 3V3A: 540 mA 3V3D: 91 mA 3V6: 78 mA 5V: 500 mA 10V: 5 mA

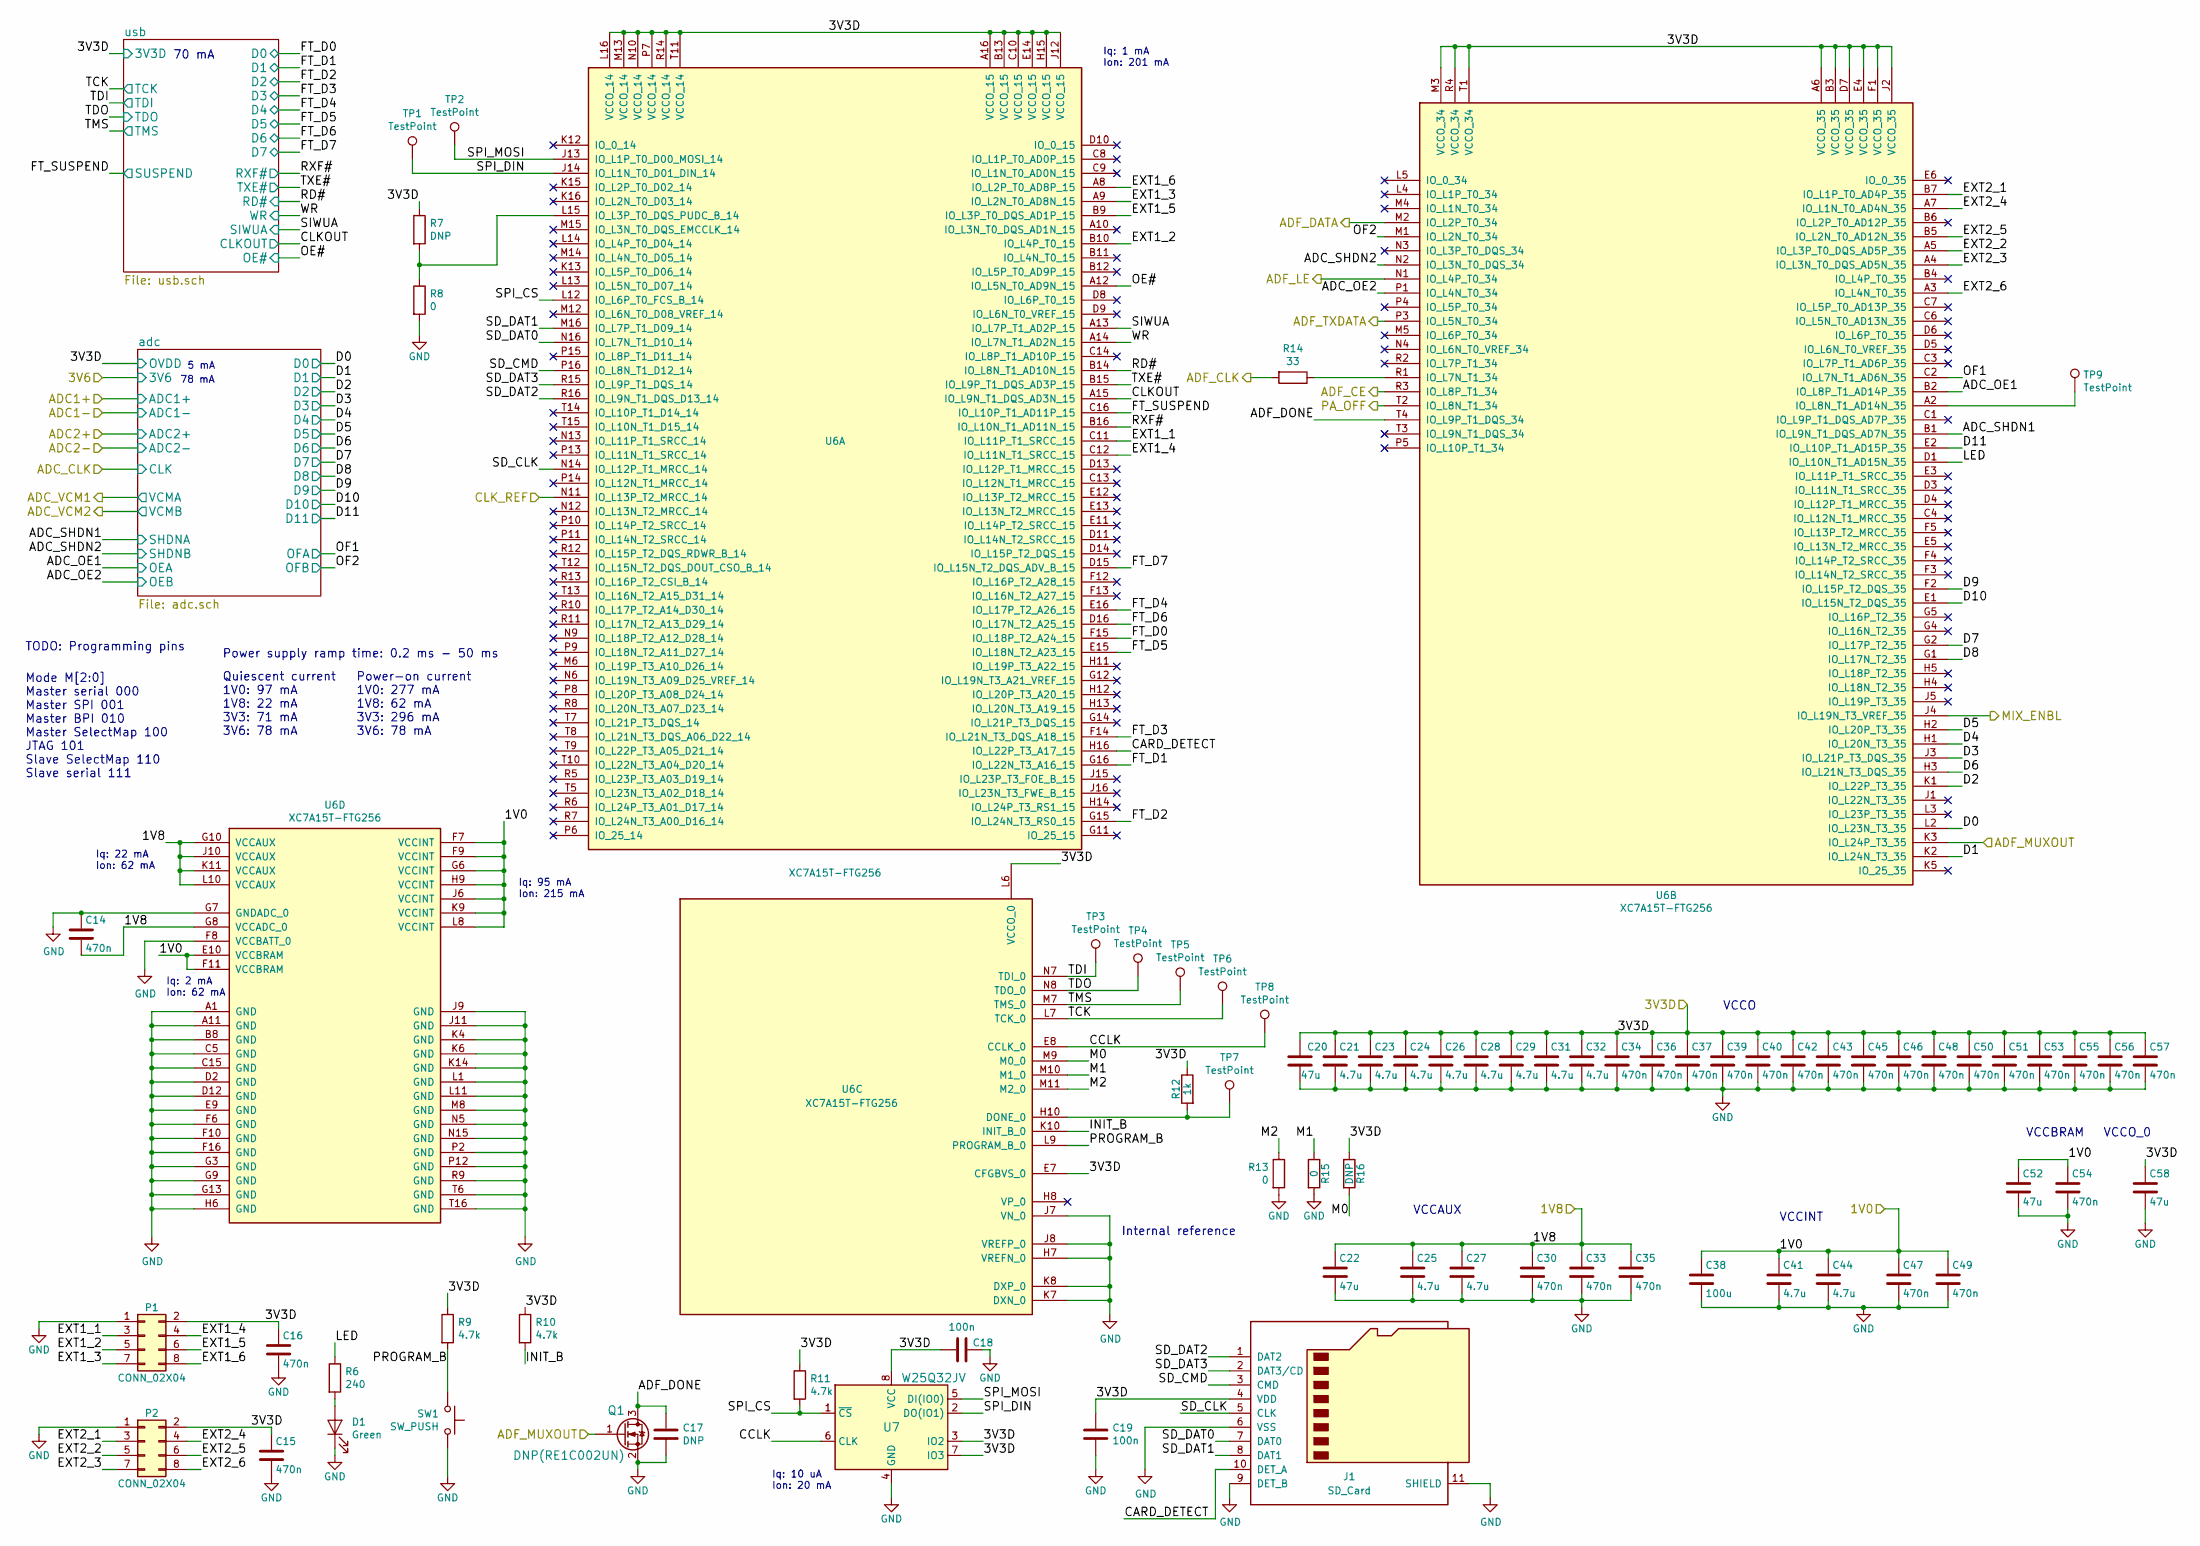
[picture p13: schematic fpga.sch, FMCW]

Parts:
C14, C15, C16, C30, C33, C34, C35, C36, C37, C39, C40, C42, C43, C45, C46, C47, C48, C49, C50, C51, C53, C54, C55, C56, C57: 470n; C_0603_1608Metric
C17: DNP; C_0402_1005Metric
C18, C19: 100n; C_0402_1005Metric
C20, C22, C52, C58: 47u; C_1206_3216Metric
C21, C23, C24, C25, C26, C27, C28, C29, C31, C32, C41, C44: 4.7u; C_0805_2012Metric
C38: 100u; C_1210_3225Metric
D1: Green; LED_0603_1608Metric
J1: SD_Card; microSD_HC_Hirose_DM3BT-DSF-PEJS
P1, P2: CONN_02X04; PinHeader_2x04_P2.54mm_Vertical_SMD
Q1: DNP(RE1C002UN); SOT-416
R6: 240; R_0402_1005Metric
R7, R16: DNP; R_0402_1005Metric
R8, R13, R15: 0; R_0402_1005Metric
R9, R10, R11: 4.7k; R_0402_1005Metric
R12: 1k; R_0402_1005Metric
R14: 33; R_0402_1005Metric
SW1: SW_PUSH; SW_SPST_PTS810
TP1, TP2, TP3, TP4, TP5, TP6, TP7, TP8, TP9: TestPoint; TestPoint_Pad_D1.0mm
U6: XC7A15T-FTG256; FTG256
U7: W25Q32JV; SOIJ-8_5.3x5.3mm_P1.27mm

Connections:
/1V0: C38.1, C41.1, C44.1, C47.1, C49.1, C52.1, C54.1, U6.E10 (VCCBRAM), U6.F7 (VCCINT), U6.F9 (VCCINT), U6.F11 (VCCBRAM), U6.G6 (VCCINT), U6.H9 (VCCINT), U6.J6 (VCCINT), U6.K9 (VCCINT), U6.L8 (VCCINT); also elsewhere on the board
/1V8: C14.2, C22.1, C25.1, C27.1, C30.1, C33.1, C35.1, U6.G8 (VCCADC_0), U6.G10 (VCCAUX), U6.J10 (VCCAUX), U6.K11 (VCCAUX), U6.L10 (VCCAUX); also elsewhere on the board
/3V3D: C15.1, C16.1, C18.2, C19.1, C20.1, C21.1, C23.1, C24.1, C26.1, C28.1, C29.1, C31.1, C32.1, C34.1, C36.1, C37.1, C39.1, C40.1, C42.1, C43.1, C45.1, C46.1, C48.1, C50.1, C51.1, C53.1, C55.1, C56.1, C57.1, C58.1, J1.4 (VDD), P1.2, P2.2, R7.1, R9.1, R10.1, R11.1, R12.1, R16.1, U6.A6 (VCCO_35), U6.A16 (VCCO_15), U6.B3 (VCCO_35), U6.B13 (VCCO_15), U6.C10 (VCCO_15), U6.D7 (VCCO_35), U6.E4 (VCCO_35), U6.E7 (CFGBVS_0), U6.E14 (VCCO_15), U6.F1 (VCCO_35), U6.H15 (VCCO_15), U6.J2 (VCCO_35), U6.J12 (VCCO_15), U6.L6 (VCCO_0), U6.L16 (VCCO_14), U6.M3 (VCCO_34), U6.M13 (VCCO_14), U6.N10 (VCCO_14), U6.P7 (VCCO_14), U6.R4 (VCCO_34), U6.R14 (VCCO_14), U6.T1 (VCCO_34), U6.T11 (VCCO_14), U7.3 (IO2), U7.7 (IO3), U7.8 (VCC); also elsewhere on the board
/ADF_CE: U6.R3 (IO_L8P_T1_34); also elsewhere on the board
/ADF_CLK: R14.2; also elsewhere on the board
/ADF_DATA: U6.M2 (IO_L2P_T0_34); also elsewhere on the board
/ADF_LE: U6.N1 (IO_L4P_T0_34); also elsewhere on the board
/ADF_MUXOUT: Q1.1 (G), U6.K3 (IO_L24P_T3_35); also elsewhere on the board
/ADF_TXDATA: U6.P3 (IO_L5N_T0_34); also elsewhere on the board
/FPGA_REF: U6.N11 (IO_L13P_T2_MRCC_14); also elsewhere on the board
/MIX_ENBL: U6.J4 (IO_L19N_T3_VREF_35); also elsewhere on the board
/PA_OFF: U6.T2 (IO_L8N_T1_34); also elsewhere on the board
/fpga/ADC_OE1: U6.B2 (IO_L8P_T1_AD14P_35); also elsewhere on the board
/fpga/ADC_OE2: U6.P1 (IO_L4N_T0_34); also elsewhere on the board
/fpga/ADC_SHDN1: U6.B1 (IO_L9N_T1_DQS_AD7N_35); also elsewhere on the board
/fpga/ADC_SHDN2: U6.N2 (IO_L3N_T0_DQS_34); also elsewhere on the board
/fpga/ADF_DONE: C17.1, Q1.3 (D), U6.T4 (IO_L9P_T1_DQS_34)
/fpga/CARD_DETECT: J1.10 (DET_A), U6.H16 (IO_L22P_T3_A17_15)
/fpga/CCLK: TP8.1, U6.E8 (CCLK_0), U7.6 (CLK)
/fpga/CLKOUT: U6.A15 (IO_L9N_T1_DQS_AD3N_15); also elsewhere on the board
/fpga/D0: U6.L2 (IO_L23N_T3_35); also elsewhere on the board
/fpga/D1: U6.K2 (IO_L24N_T3_35); also elsewhere on the board
/fpga/D2: U6.K1 (IO_L22P_T3_35); also elsewhere on the board
/fpga/D3: U6.J3 (IO_L21P_T3_DQS_35); also elsewhere on the board
/fpga/D4: U6.H1 (IO_L20N_T3_35); also elsewhere on the board
/fpga/D5: U6.H2 (IO_L20P_T3_35); also elsewhere on the board
/fpga/D6: U6.H3 (IO_L21N_T3_DQS_35); also elsewhere on the board
/fpga/D7: U6.G2 (IO_L17P_T2_35); also elsewhere on the board
/fpga/D8: U6.G1 (IO_L17N_T2_35); also elsewhere on the board
/fpga/D9: U6.F2 (IO_L15P_T2_DQS_35); also elsewhere on the board
/fpga/D10: U6.E1 (IO_L15N_T2_DQS_35); also elsewhere on the board
/fpga/D11: U6.E2 (IO_L10P_T1_AD15P_35); also elsewhere on the board
/fpga/EXT1_1: P1.3, U6.C11 (IO_L11P_T1_SRCC_15)
/fpga/EXT1_2: P1.5, U6.B10 (IO_L4P_T0_15)
/fpga/EXT1_3: P1.7, U6.A9 (IO_L2N_T0_AD8N_15)
/fpga/EXT1_4: P1.4, U6.C12 (IO_L11N_T1_SRCC_15)
/fpga/EXT1_5: P1.6, U6.B9 (IO_L3P_T0_DQS_AD1P_15)
/fpga/EXT1_6: P1.8, U6.A8 (IO_L2P_T0_AD8P_15)
/fpga/EXT2_1: P2.3, U6.B7 (IO_L1P_T0_AD4P_35)
/fpga/EXT2_2: P2.5, U6.A5 (IO_L3P_T0_DQS_AD5P_35)
/fpga/EXT2_3: P2.7, U6.A4 (IO_L3N_T0_DQS_AD5N_35)
/fpga/EXT2_4: P2.4, U6.A7 (IO_L1N_T0_AD4N_35)
/fpga/EXT2_5: P2.6, U6.B5 (IO_L2N_T0_AD12N_35)
/fpga/EXT2_6: P2.8, U6.A3 (IO_L4N_T0_35)
/fpga/FT_D0: U6.F15 (IO_L18P_T2_A24_15); also elsewhere on the board
/fpga/FT_D1: U6.G16 (IO_L22N_T3_A16_15); also elsewhere on the board
/fpga/FT_D2: U6.G15 (IO_L24N_T3_RS0_15); also elsewhere on the board
/fpga/FT_D3: U6.F14 (IO_L21N_T3_DQS_A18_15); also elsewhere on the board
/fpga/FT_D4: U6.E16 (IO_L17P_T2_A26_15); also elsewhere on the board
/fpga/FT_D5: U6.E15 (IO_L18N_T2_A23_15); also elsewhere on the board
/fpga/FT_D6: U6.D16 (IO_L17N_T2_A25_15); also elsewhere on the board
/fpga/FT_D7: U6.D15 (IO_L15N_T2_DQS_ADV_B_15); also elsewhere on the board
/fpga/FT_SUSPEND: U6.C16 (IO_L10P_T1_AD11P_15); also elsewhere on the board
/fpga/INIT_B: R10.2, U6.K10 (INIT_B_0)
/fpga/LED: R6.1, U6.D1 (IO_L10N_T1_AD15N_35)
/fpga/M0: R16.2, U6.M9 (M0_0)
/fpga/M1: R15.1, U6.M10 (M1_0)
/fpga/M2: R13.1, U6.M11 (M2_0)
/fpga/OE#: U6.A12 (IO_L5N_T0_AD9N_15); also elsewhere on the board
/fpga/OF1: U6.C2 (IO_L7N_T1_AD6N_35); also elsewhere on the board
/fpga/OF2: U6.M1 (IO_L2N_T0_34); also elsewhere on the board
/fpga/PROGRAM_B: R9.2, SW1.1, U6.L9 (PROGRAM_B_0)
/fpga/RD#: U6.B14 (IO_L8N_T1_AD10N_15); also elsewhere on the board
/fpga/RXF#: U6.B16 (IO_L10N_T1_AD11N_15); also elsewhere on the board
/fpga/SD_CLK: J1.5 (CLK), U6.N14 (IO_L12P_T1_MRCC_14)
/fpga/SD_CMD: J1.3 (CMD), U6.P16 (IO_L8N_T1_D12_14)
/fpga/SD_DAT0: J1.7 (DAT0), U6.N16 (IO_L7N_T1_D10_14)
/fpga/SD_DAT1: J1.8 (DAT1), U6.M16 (IO_L7P_T1_D09_14)
/fpga/SD_DAT2: J1.1 (DAT2), U6.R16 (IO_L9N_T1_DQS_D13_14)
/fpga/SD_DAT3: J1.2 (DAT3/CD), U6.R15 (IO_L9P_T1_DQS_14)
/fpga/SIWUA: U6.A13 (IO_L7P_T1_AD2P_15); also elsewhere on the board
/fpga/SPI_CS: R11.2, U6.L12 (IO_L6P_T0_FCS_B_14), U7.1 (~CS)
/fpga/SPI_DIN: TP1.1, U6.J14 (IO_L1N_T0_D01_DIN_14), U7.2 (DO(IO1))
/fpga/SPI_MOSI: TP2.1, U6.J13 (IO_L1P_T0_D00_MOSI_14), U7.5 (DI(IO0))
/fpga/TCK: TP6.1, U6.L7 (TCK_0); also elsewhere on the board
/fpga/TDI: TP3.1, U6.N7 (TDI_0); also elsewhere on the board
/fpga/TDO: TP4.1, U6.N8 (TDO_0); also elsewhere on the board
/fpga/TMS: TP5.1, U6.M7 (TMS_0); also elsewhere on the board
/fpga/TXE#: U6.B15 (IO_L9P_T1_DQS_AD3P_15); also elsewhere on the board
/fpga/WR: U6.A14 (IO_L7N_T1_AD2N_15); also elsewhere on the board
GND: C14.1, C15.2, C16.2, C17.2, C18.1, C19.2, C20.2, C21.2, C22.2, C23.2, C24.2, C25.2, C26.2, C27.2, C28.2, C29.2, C30.2, C31.2, C32.2, C33.2, C34.2, C35.2, C36.2, C37.2, C38.2, C39.2, C40.2, C41.2, C42.2, C43.2, C44.2, C45.2, C46.2, C47.2, C48.2, C49.2, C50.2, C51.2, C52.2, C53.2, C54.2, C55.2, C56.2, C57.2, C58.2, D1.1 (K), J1.6 (VSS), J1.9 (DET_B), J1.11 (SHIELD), P1.1, P2.1, Q1.2 (S), R8.2, R13.2, R15.2, SW1.2, U6.A1 (GND), U6.A11 (GND), U6.B8 (GND), U6.C5 (GND), U6.C15 (GND), U6.D2 (GND), U6.D12 (GND), U6.E9 (GND), U6.F6 (GND), U6.F8 (VCCBATT_0), U6.F10 (GND), U6.F16 (GND), U6.G3 (GND), U6.G7 (GNDADC_0), U6.G9 (GND), U6.G13 (GND), U6.H6 (GND), U6.H7 (VREFN_0), U6.J7 (VN_0), U6.J8 (VREFP_0), U6.J9 (GND), U6.J11 (GND), U6.K4 (GND), U6.K6 (GND), U6.K7 (DXN_0), U6.K8 (DXP_0), U6.K14 (GND), U6.L1 (GND), U6.L11 (GND), U6.M8 (GND), U6.N5 (GND), U6.N15 (GND), U6.P2 (GND), U6.P12 (GND), U6.R9 (GND), U6.T6 (GND), U6.T16 (GND), U7.4 (GND); also elsewhere on the board
unnamed: D1.2 (A), R6.2
unnamed: R7.2, R8.1, U6.L15 (IO_L3P_T0_DQS_PUDC_B_14)
unnamed: R12.2, TP7.1, U6.H10 (DONE_0)
unnamed: R14.1, U6.R1 (IO_L7N_T1_34)
unnamed: TP9.1, U6.A2 (IO_L8N_T1_AD14N_35)

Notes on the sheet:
VCCINT
VCCBRAM
VCCAUX
VCCO_0
VCCO
Internal reference
Quiescent current 1V0: 97 mA 1V8: 22 mA 3V3: 71 mA 3V6: 78 mA
Power-on current 1V0: 277 mA 1V8: 62 mA 3V3: 296 mA 3V6: 78 mA
Power supply ramp time: 0.2 ms - 50 ms
78 mA
TODO: Programming pins
Mode M[2:0] Master serial 000 Master SPI 001 Master BPI 010 Master SelectMap 100 JTAG 101 Slave SelectMap 110 Slave serial 111
70 mA
5 mA
Iq: 95 mA Ion: 215 mA
Iq: 2 mA Ion: 62 mA
Iq: 22 mA Ion: 62 mA
Iq: 1 mA Ion: 201 mA
Iq: 10 uA Ion: 20 mA

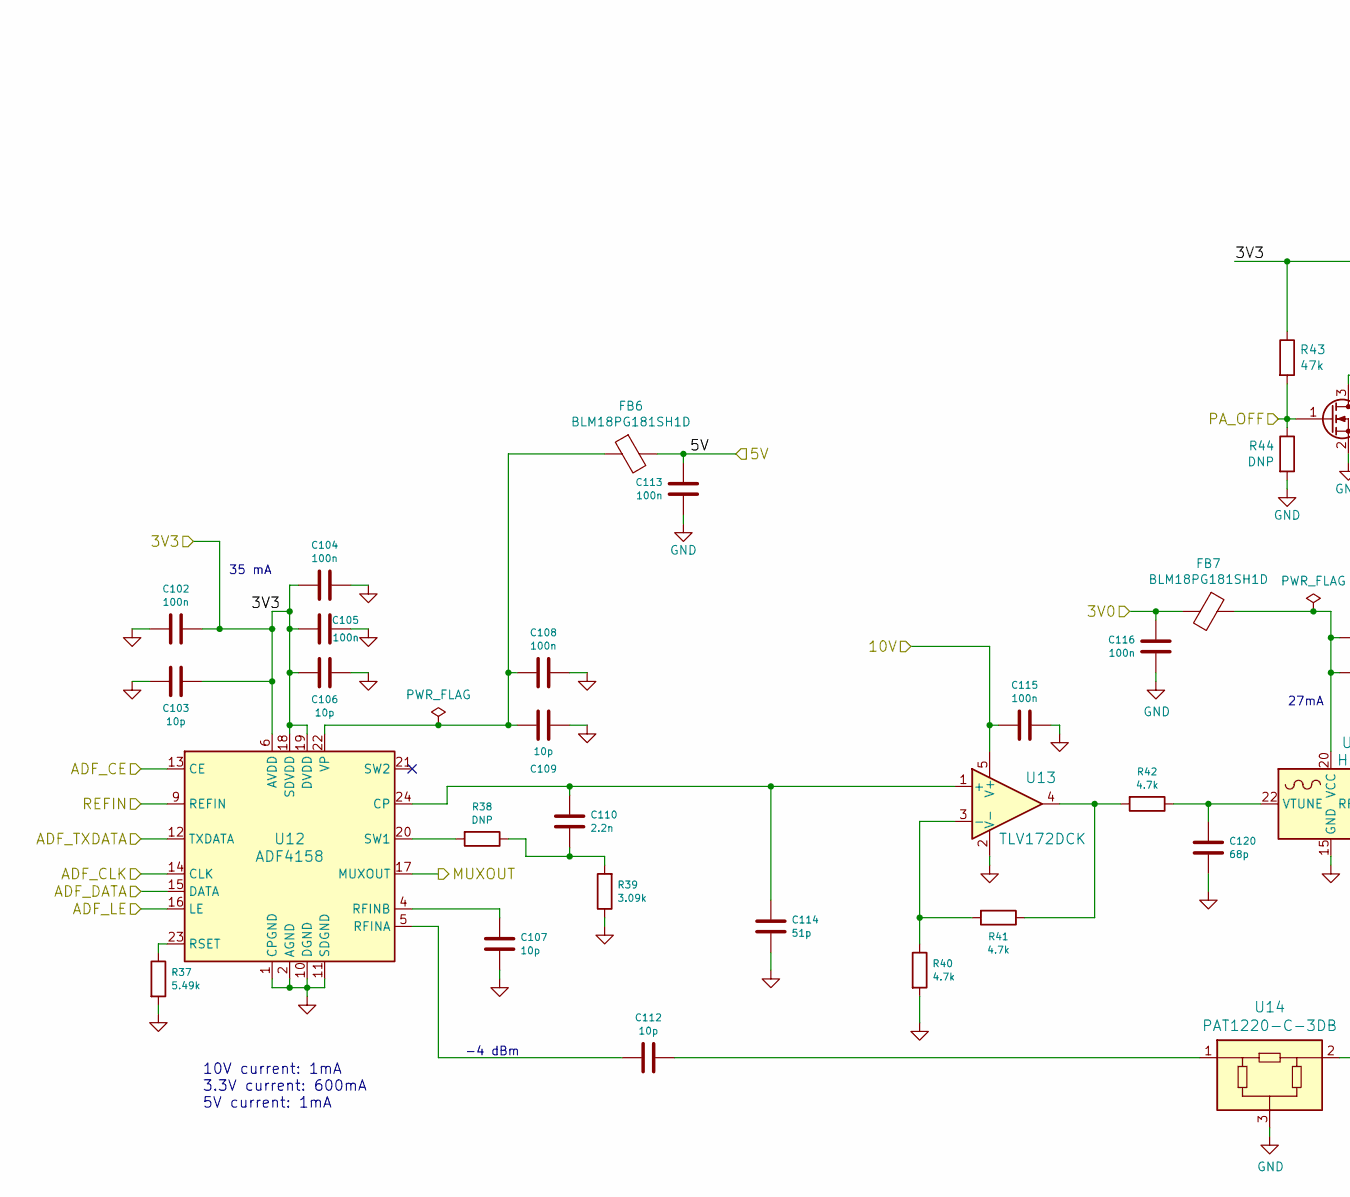
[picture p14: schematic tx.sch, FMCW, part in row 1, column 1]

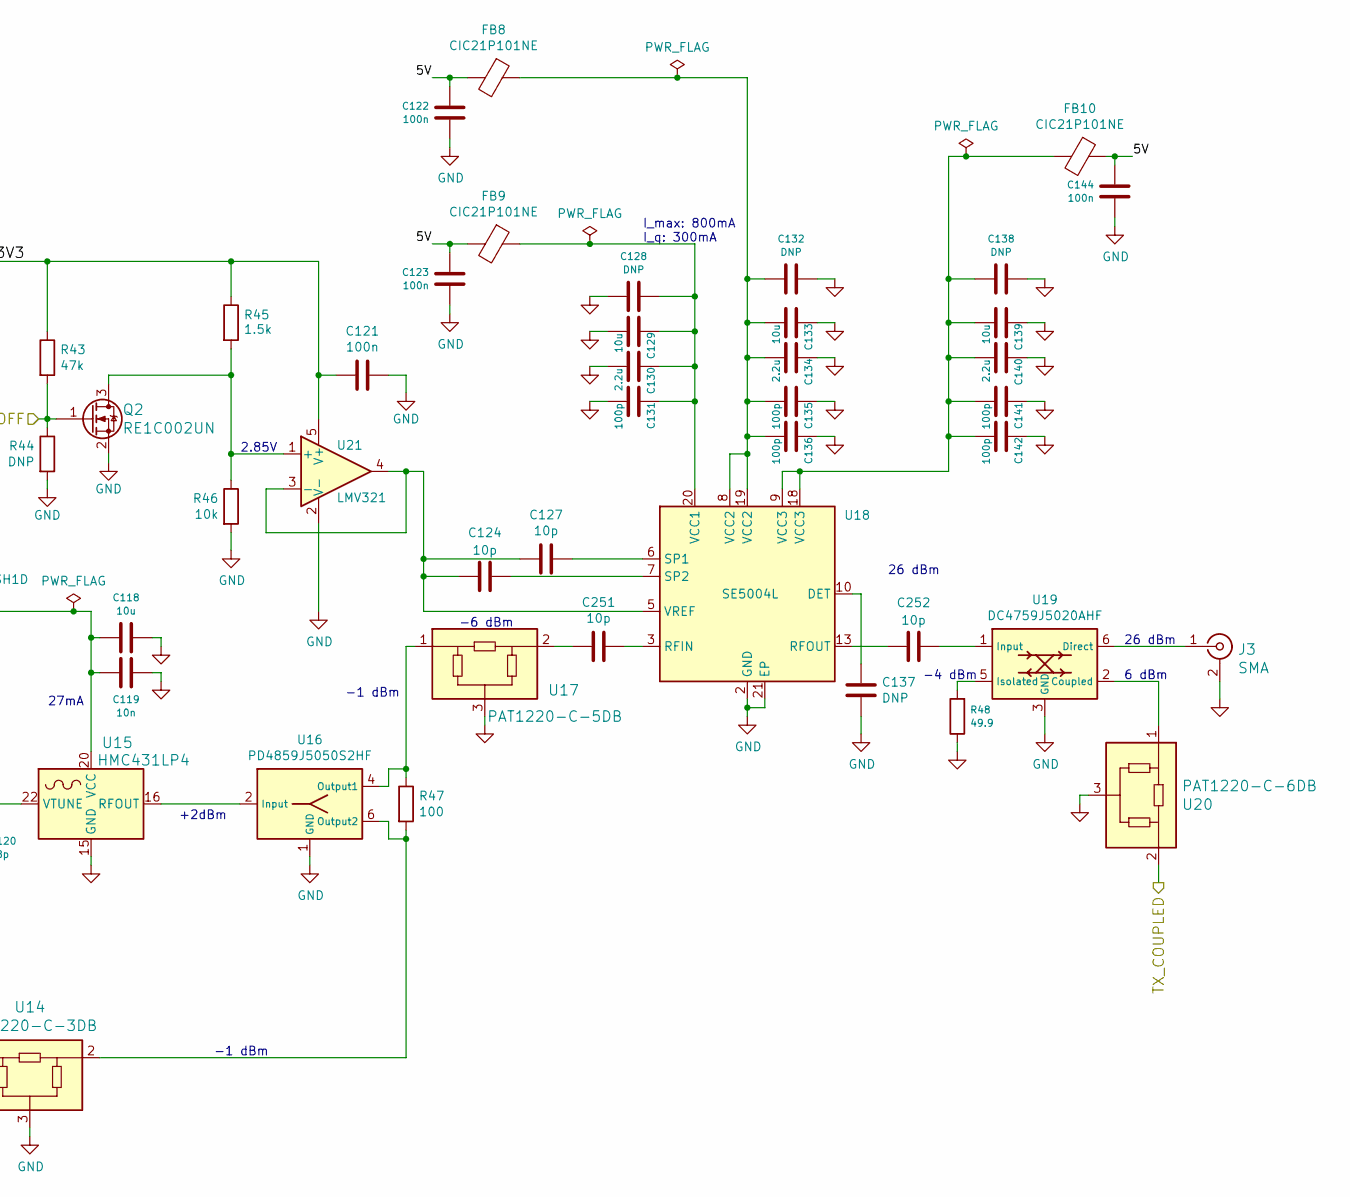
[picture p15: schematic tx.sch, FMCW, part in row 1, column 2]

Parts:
C102, C104, C105, C108, C113, C115, C116, C121, C122, C123, C144: 100n; C_0402_1005Metric
C103, C106, C107, C109, C112, C124, C127, C251, C252: 10p; C_0402_1005Metric
C110: 2.2n; C_0402_1005Metric
C114: 51p; C_0402_1005Metric
C118, C129, C133, C139: 10u; C_0805_2012Metric
C119: 10n; C_0402_1005Metric
C120: 68p; C_0402_1005Metric
C128, C132, C137, C138: DNP; C_0603_1608Metric
C130, C134, C140: 2.2u; C_0603_1608Metric
C131, C135, C136, C141, C142: 100p; C_0402_1005Metric
FB6, FB7: BLM18PG181SH1D; L_0603_1608Metric
FB8, FB9, FB10: CIC21P101NE; L_0805_2012Metric
J3: SMA; CONSMA003.062
Q2: RE1C002UN; SOT-416
R37: 5.49k; R_0402_1005Metric
R38, R44: DNP; R_0402_1005Metric
R39: 3.09k; R_0402_1005Metric
R40, R41, R42: 4.7k; R_0402_1005Metric
R43: 47k; R_0402_1005Metric
R45: 1.5k; R_0402_1005Metric
R46: 10k; R_0402_1005Metric
R47: 100; R_0603_1608Metric
R48: 49.9; R_0402_1005Metric
U12: ADF4158; LFCSP-24-1EP_4x4mm_P0.5mm_EP2.5x2.5mm_ThermalVias
U13: TLV172DCK; SOT-353_SC-70-5
U14: PAT1220-C-3DB; RF_Attenuator_Susumu_PAT1220
U15: HMC431LP4; QFN-24-1EP_4x4mm_P0.5mm_EP2.8x2.8mm_ThermalVias
U16: PD4859J5050S2HF; Anaren_0805_2012Metric-6
U17: PAT1220-C-5DB; RF_Attenuator_Susumu_PAT1220
U18: SE5004L; QFN-20-1EP_4x4mm_P0.5mm_EP2.5x2.5mm_ThermalVias
U19: DC4759J5020AHF; Anaren_0805_2012Metric-6
U20: PAT1220-C-6DB; RF_Attenuator_Susumu_PAT1220
U21: LMV321; SOT-23-5

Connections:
/3V0: C116.1, FB7.2; also elsewhere on the board
/3V3A: C102.1, C103.1, C104.1, C105.1, C106.1, C121.2, R43.1, R45.1, U12.6 (AVDD), U12.7 (AVDD), U12.8 (AVDD), U12.18 (SDVDD), U12.19 (DVDD), U21.5 (V+); also elsewhere on the board
/5V: C113.1, C122.1, C123.1, C144.1, FB6.2, FB8.2, FB9.2, FB10.1; also elsewhere on the board
/10V: C115.2, U13.5 (V+); also elsewhere on the board
/ADF_CE: U12.13 (CE); also elsewhere on the board
/ADF_CLK: U12.14 (CLK); also elsewhere on the board
/ADF_DATA: U12.15 (DATA); also elsewhere on the board
/ADF_LE: U12.16 (LE); also elsewhere on the board
/ADF_MUXOUT: U12.17 (MUXOUT); also elsewhere on the board
/ADF_REF: U12.9 (REFIN); also elsewhere on the board
/ADF_TXDATA: U12.12 (TXDATA); also elsewhere on the board
/LO: U20.2; also elsewhere on the board
/PA_OFF: Q2.1 (G), R43.2, R44.1; also elsewhere on the board
GND: C102.2, C103.2, C104.2, C105.2, C106.2, C107.1, C108.2, C109.2, C113.2, C114.2, C115.1, C116.2, C118.1, C119.1, C120.2, C121.1, C122.2, C123.2, C128.2, C129.2, C130.2, C131.2, C132.1, C133.1, C134.1, C135.1, C136.1, C137.2, C138.1, C139.1, C140.1, C141.1, C142.1, C144.2, J3.2 (Ext), Q2.2 (S), R37.2, R39.1, R40.2, R44.2, R46.2, R48.1, U12.1 (CPGND), U12.2 (AGND), U12.3 (AGND), U12.10 (DGND), U12.11 (SDGND), U12.25 (AGND), U13.2 (V-), U14.3, U15.15 (GND), U15.25 (GND), U16.1 (GND), U16.3 (GND), U16.5 (GND), U17.3, U18.2 (GND), U18.4 (GND), U18.11 (GND), U18.12 (GND), U18.14 (GND), U18.15 (GND), U18.16 (GND), U18.17 (GND), U18.21 (EP), U19.3 (GND), U19.4 (GND), U20.3, U21.2 (V-); also elsewhere on the board
unnamed: C107.2, U12.4 (RFINB)
unnamed: C108.1, C109.1, FB6.1, U12.22 (VP)
unnamed: C110.1, C114.1, U12.24 (CP), U13.1 (+)
unnamed: C110.2, R38.1, R39.2
unnamed: C112.1, U14.1
unnamed: C112.2, U12.5 (RFINA)
unnamed: C118.2, C119.2, FB7.1, U15.20 (VCC)
unnamed: C120.1, R42.1, U15.22 (VTUNE)
unnamed: C124.1, U18.7 (SP2)
unnamed: C124.2, C127.2, U18.5 (VREF), U21.3 (-), U21.4
unnamed: C127.1, U18.6 (SP1)
unnamed: C128.1, C129.1, C130.1, C131.1, FB9.1, U18.20 (VCC1)
unnamed: C132.2, C133.2, C134.2, C135.2, C136.2, FB8.1, U18.8 (VCC2), U18.19 (VCC2)
unnamed: C137.1, U18.10 (DET)
unnamed: C138.2, C139.2, C140.2, C141.2, C142.2, FB10.2, U18.9 (VCC3), U18.18 (VCC3)
unnamed: C251.1, U18.3 (RFIN)
unnamed: C251.2, U17.2
unnamed: C252.1, U19.1 (Input)
unnamed: C252.2, U18.13 (RFOUT)
unnamed: J3.1 (In), U19.6 (Direct)
unnamed: Q2.3 (D), R45.2, R46.1, U21.1 (+)
unnamed: R37.1, U12.23 (RSET)
unnamed: R38.2, U12.20 (SW1)
unnamed: R40.1, R41.2, U13.3 (-)
unnamed: R41.1, R42.2, U13.4
unnamed: R47.1, U16.4 (Output1), U17.1
unnamed: R47.2, U14.2, U16.6 (Output2)
unnamed: R48.2, U19.5 (Isolated)
unnamed: U15.16 (RFOUT), U16.2 (Input)
unnamed: U19.2 (Coupled), U20.1

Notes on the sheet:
-4 dBm
27mA
26 dBm
35 mA
I_max: 800mA I_q: 300mA
10V current: 1mA 3.3V current: 600mA 5V current: 1mA
2.85V
+2dBm
-1 dBm
6 dBm
-6 dBm

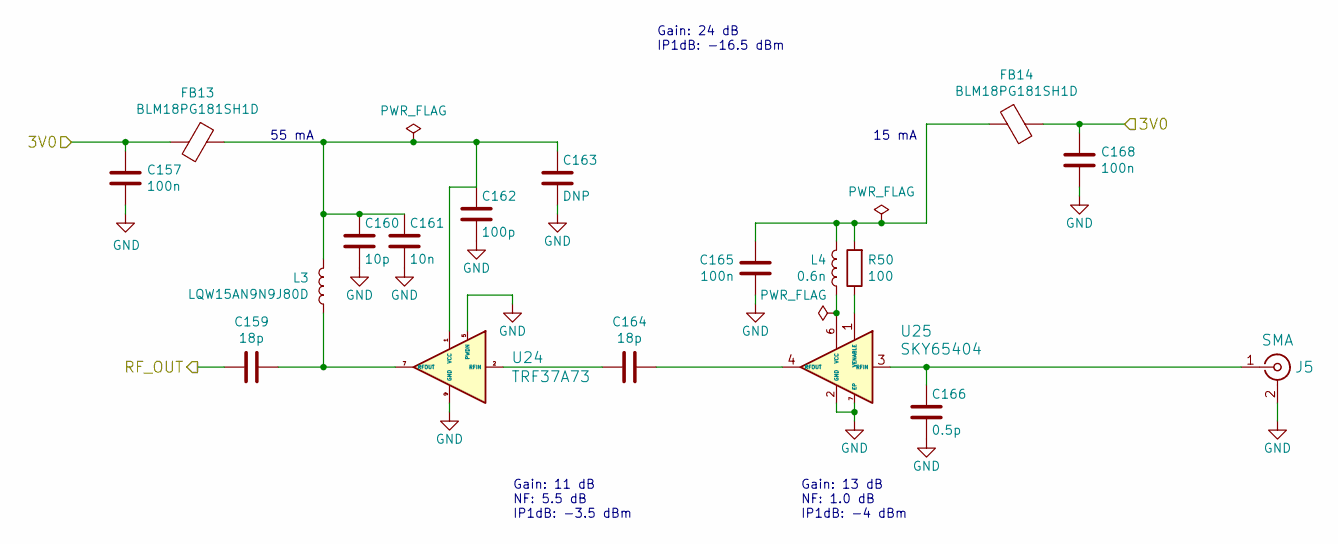
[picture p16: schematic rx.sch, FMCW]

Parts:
C145, C153, C156: 100n; C_0402_1005Metric
C147, C152: 18p; C_0402_1005Metric
C148: 10p; C_0402_1005Metric
C149: 10n; C_0402_1005Metric
C150: 100p; C_0402_1005Metric
C154: 0.5p; C_0402_1005Metric
C163: DNP; C_0603_1608Metric
FB13, FB14: BLM18PG181SH1D; L_0603_1608Metric
J4: SMA; CONSMA003.062
L1: LQW15AN9N9J80D; L_0402_1005Metric
L2: 0.6n; L_0402_1005Metric
R49: 100; R_0402_1005Metric
U22: TRF37A73; WSON-8-1EP_2x2mm_P0.5mm_EP0.9x1.6mm
U23: SKY65404; Skyworks_DFN-6-1EP_1.5x1.5mm_P0.5mm_EP0.7x1.2mm

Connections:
/3V0: C145.1, C156.1, FB13.2, FB14.2; also elsewhere on the board
/RF1: C147.2; also elsewhere on the board
GND: C145.2, C148.2, C149.2, C150.2, C153.2, C154.2, C156.2, C163.2, J4.2 (Ext), U22.5 (PWDN), U22.9 (GND), U23.2 (GND), U23.5 (GND), U23.7 (EP); also elsewhere on the board
unnamed: C147.1, L1.1, U22.7 (RFOUT)
unnamed: C152.1, U23.4 (RFOUT)
unnamed: C152.2, U22.2 (RFIN)
unnamed: C154.1, J4.1 (In), U23.3 (RFIN)
unnamed: L2.1, U23.6 (VCC)
unnamed: R49.1, U23.1 (VENABLE)

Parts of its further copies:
C151: DNP; C_0603_1608Metric
C157, C165, C168: 100n; C_0402_1005Metric
C159, C164: 18p; C_0402_1005Metric
C160: 10p; C_0402_1005Metric
C161: 10n; C_0402_1005Metric
C162: 100p; C_0402_1005Metric
C166: 0.5p; C_0402_1005Metric
FB11, FB12: BLM18PG181SH1D; L_0603_1608Metric
J5: SMA; CONSMA003.062
L3: LQW15AN9N9J80D; L_0402_1005Metric
L4: 0.6n; L_0402_1005Metric
R50: 100; R_0402_1005Metric
U24: TRF37A73; WSON-8-1EP_2x2mm_P0.5mm_EP0.9x1.6mm
U25: SKY65404; Skyworks_DFN-6-1EP_1.5x1.5mm_P0.5mm_EP0.7x1.2mm

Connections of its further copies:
/3V0: C157.1, C168.1, FB11.2, FB12.2; also elsewhere on the board
/RF2: C159.2; also elsewhere on the board
GND: C151.2, C157.2, C160.2, C161.2, C162.2, C165.2, C166.2, C168.2, J5.2 (Ext), U24.5 (PWDN), U24.9 (GND), U25.2 (GND), U25.5 (GND), U25.7 (EP); also elsewhere on the board
unnamed: C159.1, L3.1, U24.7 (RFOUT)
unnamed: C164.1, U25.4 (RFOUT)
unnamed: C164.2, U24.2 (RFIN)
unnamed: C166.1, J5.1 (In), U25.3 (RFIN)
unnamed: L4.1, U25.6 (VCC)
unnamed: R50.1, U25.1 (VENABLE)

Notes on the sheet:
55 mA
15 mA
Gain: 13 dB NF: 1.0 dB IP1dB: -4 dBm
Gain: 11 dB NF: 5.5 dB IP1dB: -3.5 dBm
Gain: 24 dB IP1dB: -16.5 dBm

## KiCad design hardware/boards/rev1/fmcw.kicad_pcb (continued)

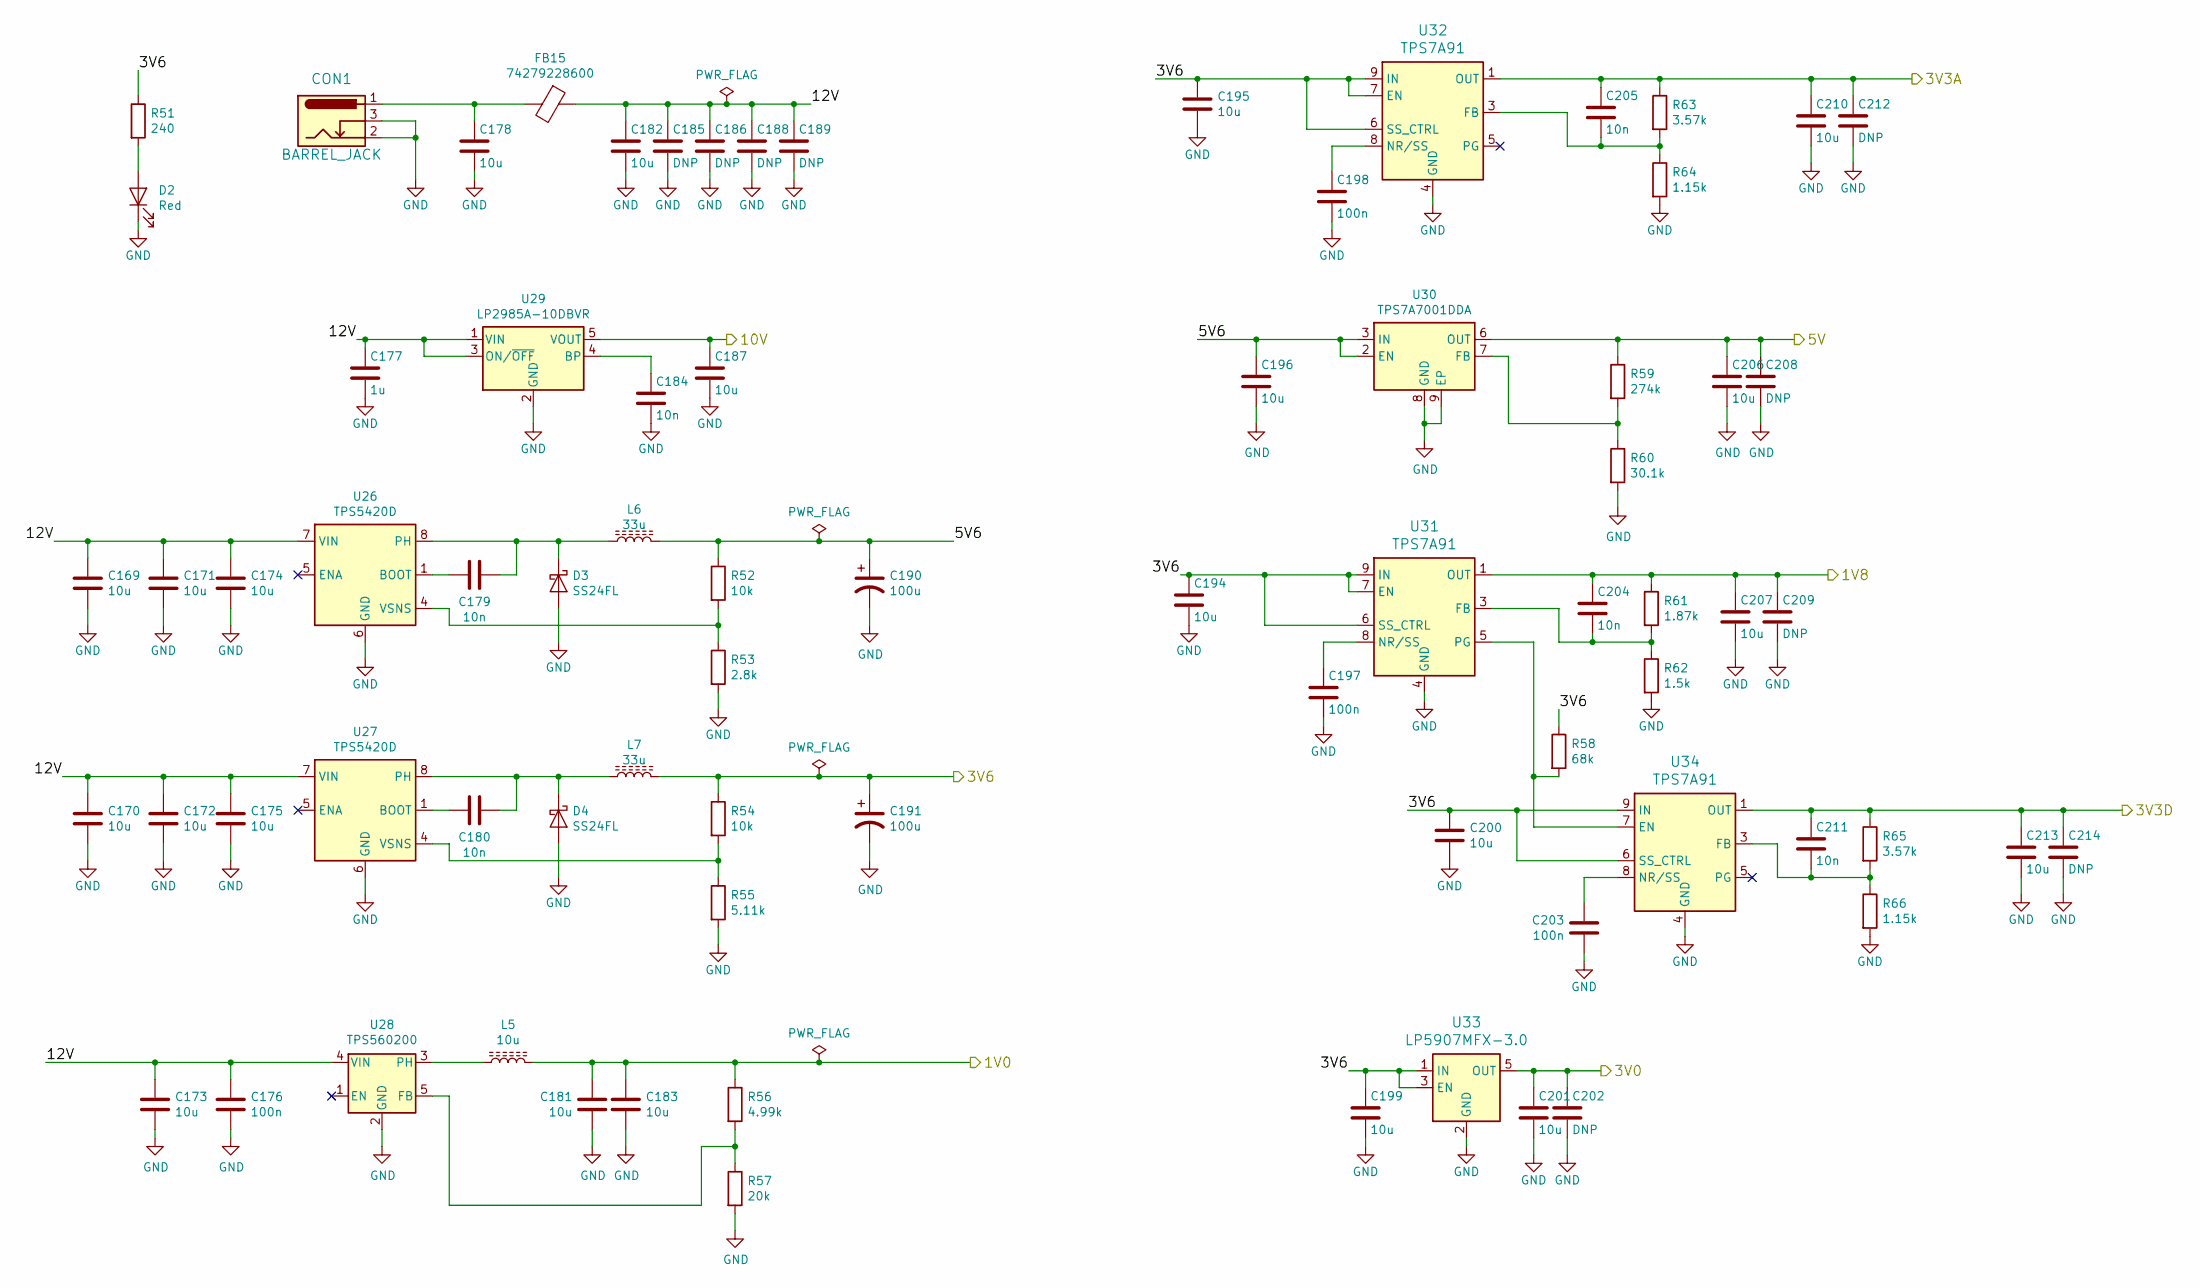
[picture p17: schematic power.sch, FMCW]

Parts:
C169, C170, C171, C172, C173, C174, C175, C178, C181, C182, C183, C187, C194, C195, C196, C199, C200, C201, C206, C207, C210, C213: 10u; C_0805_2012Metric
C176, C197, C198, C203: 100n; C_0402_1005Metric
C177: 1u; C_0603_1608Metric
C179, C180, C184, C204, C205, C211: 10n; C_0402_1005Metric
C185, C186, C188, C189, C202, C208, C209, C212, C214: DNP; C_0805_2012Metric
C190, C191: 100u; CP_EIA-7343-31_Kemet-D
CON1: BARREL_JACK; BarrelJack_Wuerth_6941xx301002
D2: Red; LED_0603_1608Metric
D3, D4: SS24FL; SOD-123F
FB15: 74279228600; L_0603_1608Metric
L5: 10u; L_Wuerth_WE-PD-Typ-7345
L6, L7: 33u; L_Bourns_SRR1210A
R51: 240; R_0402_1005Metric
R52, R54: 10k; R_0402_1005Metric
R53: 2.8k; R_0402_1005Metric
R55: 5.11k; R_0402_1005Metric
R56: 4.99k; R_0402_1005Metric
R57: 20k; R_0402_1005Metric
R58: 68k; R_0402_1005Metric
R59: 274k; R_0402_1005Metric
R60: 30.1k; R_0402_1005Metric
R61: 1.87k; R_0402_1005Metric
R62: 1.5k; R_0402_1005Metric
R63, R65: 3.57k; R_0402_1005Metric
R64, R66: 1.15k; R_0402_1005Metric
U26, U27: TPS5420D; SOIC-8_3.9x4.9mm_P1.27mm
U28: TPS560200; SOT-23-5
U29: LP2985A-10DBVR; SOT-23-5
U30: TPS7A7001DDA; TI_SO-PowerPAD-8_ThermalVias
U31, U32, U34: TPS7A91; DFN-10-1EP_2.5x2.5mm_P0.5mm_EP1.2x2mm
U33: LP5907MFX-3.0; SOT-23-5

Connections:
/1V0: C181.1, C183.1, L5.2, R56.1; also elsewhere on the board
/1V8: C204.1, C207.1, C209.1, R61.1, U31.1 (OUT), U31.2 (OUT); also elsewhere on the board
/3V0: C201.1, C202.1, U33.5 (OUT); also elsewhere on the board
/3V3A: C205.1, C210.1, C212.1, R63.1, U32.1 (OUT), U32.2 (OUT); also elsewhere on the board
/3V3D: C211.1, C213.1, C214.1, R65.1, U34.1 (OUT), U34.2 (OUT); also elsewhere on the board
/3V6: C191.1, C194.1, C195.1, C199.1, C200.1, L7.2, R51.1, R54.1, R58.1, U31.6 (SS_CTRL), U31.7 (EN), U31.9 (IN), U31.10 (IN), U32.6 (SS_CTRL), U32.7 (EN), U32.9 (IN), U32.10 (IN), U33.1 (IN), U33.3 (EN), U34.6 (SS_CTRL), U34.9 (IN), U34.10 (IN); also elsewhere on the board
/5V: C206.1, C208.1, R59.1, U30.6 (OUT); also elsewhere on the board
/10V: C187.1, U29.5 (VOUT); also elsewhere on the board
/power/5V6: C190.1, C196.1, L6.2, R52.1, U30.2 (EN), U30.3 (IN)
/power/12V: C169.1, C170.1, C171.1, C172.1, C173.1, C174.1, C175.1, C176.1, C177.1, C182.1, C185.1, C186.1, C188.1, C189.1, FB15.1, U26.7 (VIN), U27.7 (VIN), U28.4 (VIN), U29.1 (VIN), U29.3 (ON/~OFF~)
GND: C169.2, C170.2, C171.2, C172.2, C173.2, C174.2, C175.2, C176.2, C177.2, C178.2, C181.2, C182.2, C183.2, C184.2, C185.2, C186.2, C187.2, C188.2, C189.2, C190.2, C191.2, C194.2, C195.2, C196.2, C197.2, C198.2, C199.2, C200.2, C201.2, C202.2, C203.2, C206.2, C207.2, C208.2, C209.2, C210.2, C212.2, C213.2, C214.2, CON1.2, CON1.3, D2.1 (K), D3.2 (A), D4.2 (A), R53.2, R55.2, R57.2, R60.2, R62.2, R64.2, R66.2, U26.6 (GND), U27.6 (GND), U28.2 (GND), U29.2 (GND), U30.8 (GND), U30.9 (EP), U31.4 (GND), U31.11 (GND), U32.4 (GND), U32.11 (GND), U33.2 (GND), U34.4 (GND), U34.11 (GND); also elsewhere on the board
unnamed: C178.1, CON1.1, FB15.2
unnamed: C179.1, D3.1 (K), L6.1, U26.8 (PH)
unnamed: C179.2, U26.1 (BOOT)
unnamed: C180.1, D4.1 (K), L7.1, U27.8 (PH)
unnamed: C180.2, U27.1 (BOOT)
unnamed: C184.1, U29.4 (BP)
unnamed: C197.1, U31.8 (NR/SS)
unnamed: C198.1, U32.8 (NR/SS)
unnamed: C203.1, U34.8 (NR/SS)
unnamed: C204.2, R61.2, R62.1, U31.3 (FB)
unnamed: C205.2, R63.2, R64.1, U32.3 (FB)
unnamed: C211.2, R65.2, R66.1, U34.3 (FB)
unnamed: D2.2 (A), R51.2
unnamed: L5.1, U28.3 (PH)
unnamed: R52.2, R53.1, U26.4 (VSNS)
unnamed: R54.2, R55.1, U27.4 (VSNS)
unnamed: R56.2, R57.1, U28.5 (FB)
unnamed: R58.2, U31.5 (PG), U34.7 (EN)
unnamed: R59.2, R60.1, U30.7 (FB)

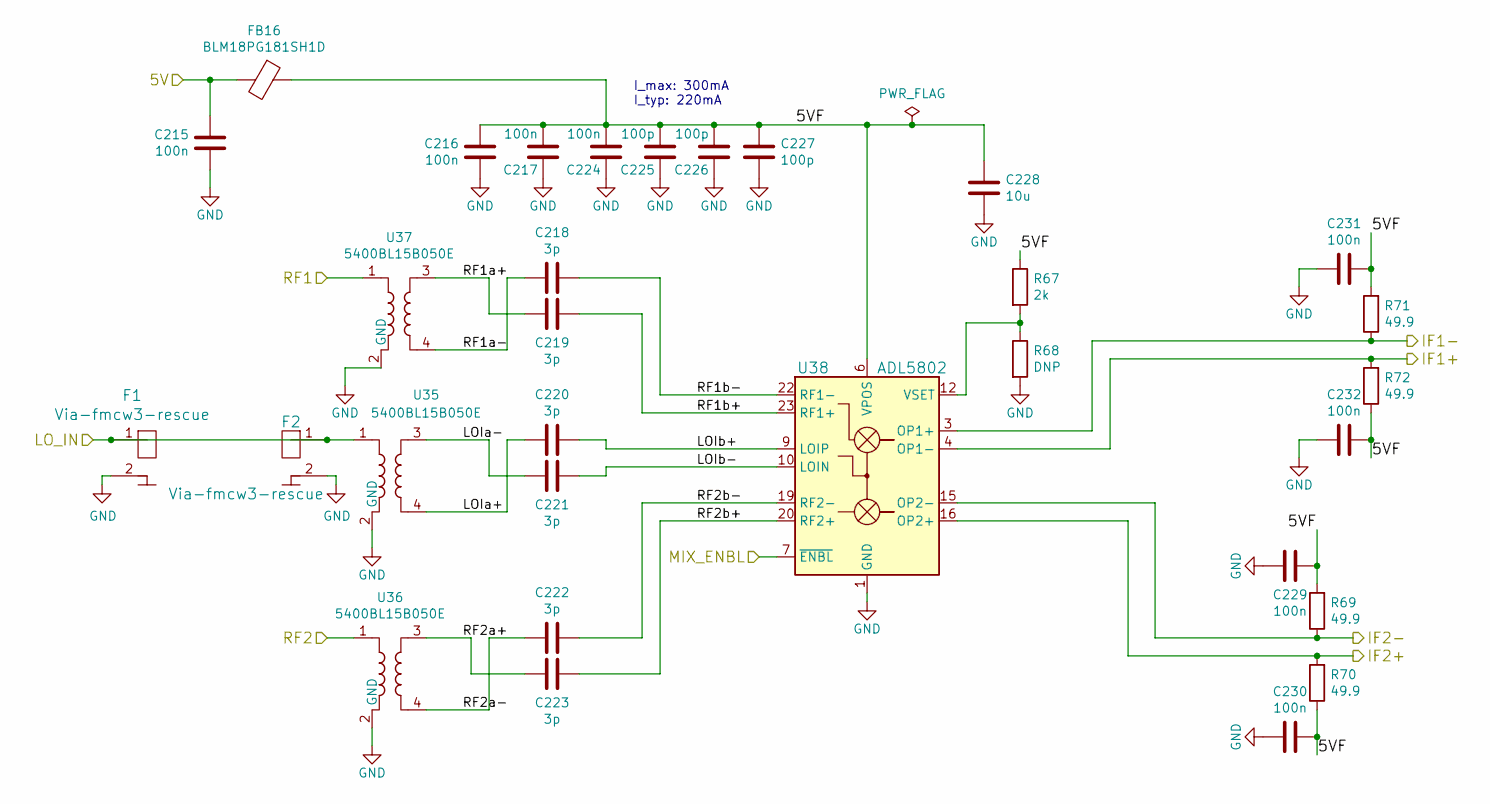
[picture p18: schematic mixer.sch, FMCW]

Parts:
C215, C216, C217, C224, C229, C230, C231, C232: 100n; C_0402_1005Metric
C218, C219, C220, C221, C222, C223: 3p; C_0402_1005Metric
C225, C226, C227: 100p; C_0402_1005Metric
C228: 10u; C_0805_2012Metric
F1, F2: Via-fmcw3-rescue; RF_via
FB16: BLM18PG181SH1D; L_0603_1608Metric
R67: 2k; R_0402_1005Metric
R68: DNP; R_0402_1005Metric
R69, R70, R71, R72: 49.9; R_0402_1005Metric
U35, U36, U37: 5400BL15B050E; Balun_Johanson_5400BL15B050E
U38: ADL5802; LFCSP-24-1EP_4x4mm_P0.5mm_EP2.5x2.5mm_ThermalVias

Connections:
/5V: C215.2, FB16.2; also elsewhere on the board
/LO: F1.1, F2.1, U35.1; also elsewhere on the board
/MIX_ENBL: U38.7 (~ENBL); also elsewhere on the board
/RF1: U37.1; also elsewhere on the board
/RF2: U36.1; also elsewhere on the board
/if/IF1+: R72.2, U38.4 (OP1-); also elsewhere on the board
/if/IF1-: R71.1, U38.3 (OP1+); also elsewhere on the board
/if/IF2+: R70.2, U38.16 (OP2+); also elsewhere on the board
/if/IF2-: R69.1, U38.15 (OP2-); also elsewhere on the board
/mixer/5VF: C216.2, C217.2, C224.2, C225.2, C226.2, C227.2, C228.2, C229.2, C230.2, C231.2, C232.2, FB16.1, R67.1, R69.2, R70.1, R71.2, R72.1, U38.6 (VPOS), U38.13 (VPOS), U38.24 (VPOS)
/mixer/LOIa+: C220.2, U35.4
/mixer/LOIa-: C221.2, U35.3
/mixer/LOIb+: C220.1, U38.9 (LOIP)
/mixer/LOIb-: C221.1, U38.10 (LOIN)
/mixer/RF1a+: C219.2, U37.3
/mixer/RF1a-: C218.2, U37.4
/mixer/RF1b+: C219.1, U38.23 (RF1+)
/mixer/RF1b-: C218.1, U38.22 (RF1-)
/mixer/RF2a+: C223.2, U36.3
/mixer/RF2a-: C222.2, U36.4
/mixer/RF2b+: C223.1, U38.20 (RF2+)
/mixer/RF2b-: C222.1, U38.19 (RF2-)
GND: C215.1, C216.1, C217.1, C224.1, C225.1, C226.1, C227.1, C228.1, C229.1, C230.1, C231.1, C232.1, F1.2, F2.2, R68.2, U35.2 (GND), U35.5 (GND), U36.2 (GND), U36.5 (GND), U37.2 (GND), U37.5 (GND), U38.1 (GND), U38.2 (GND), U38.5 (GND), U38.8 (GND), U38.11 (GND), U38.14 (GND), U38.17 (GND), U38.18 (GND), U38.21 (GND), U38.25 (GND); also elsewhere on the board
unnamed: R67.2, R68.1, U38.12 (VSET)

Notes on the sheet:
I_max: 300mA I_typ: 220mA

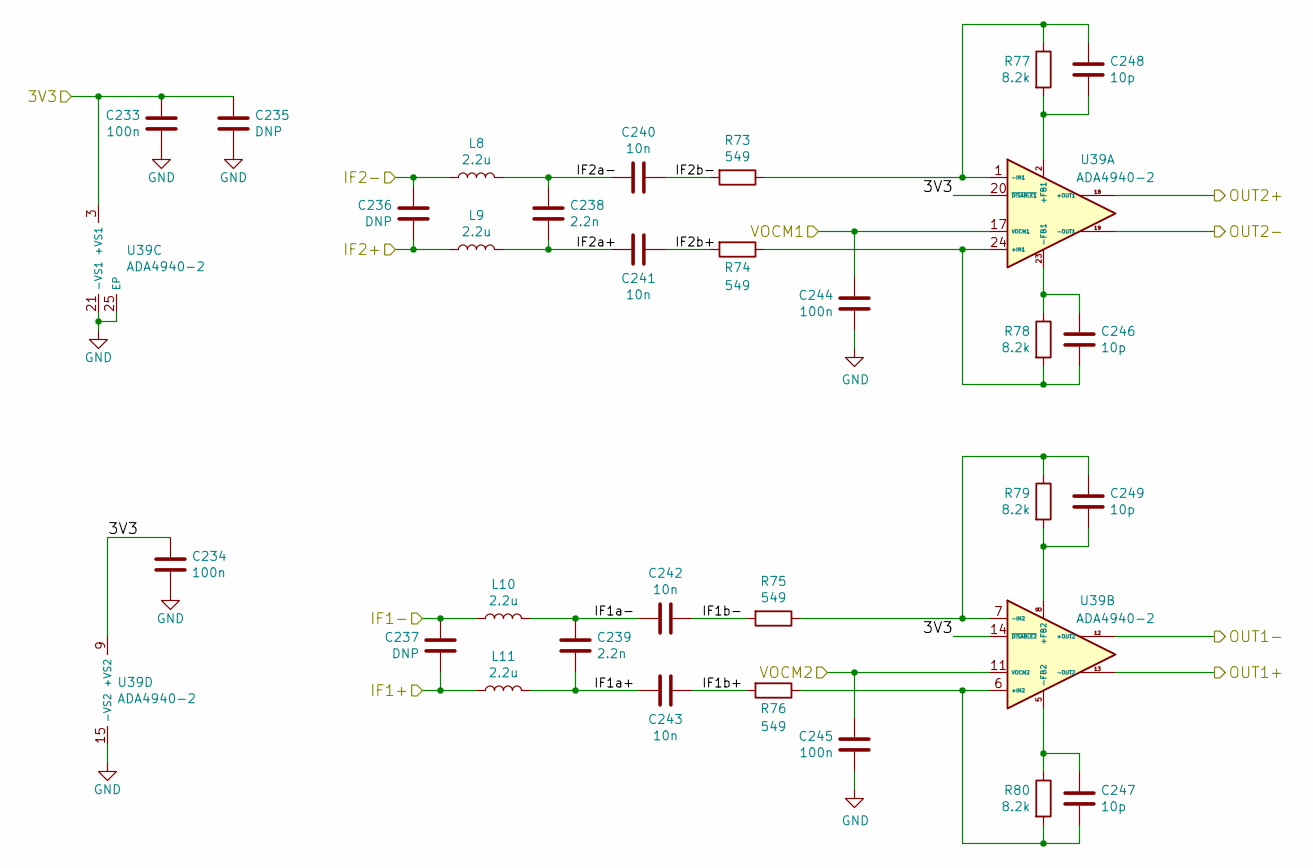
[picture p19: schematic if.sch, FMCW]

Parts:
C233, C234, C244, C245: 100n; C_0402_1005Metric
C235: DNP; C_0805_2012Metric
C236, C237: DNP; C_0402_1005Metric
C238, C239: 2.2n; C_0402_1005Metric
C240, C241, C242, C243: 10n; C_0402_1005Metric
C246, C247, C248, C249: 10p; C_0402_1005Metric
L8, L9, L10, L11: 2.2u; L_0805_2012Metric
R73, R74, R75, R76: 549; R_0402_1005Metric
R77, R78, R79, R80: 8.2k; R_0402_1005Metric
U39: ADA4940-2; LFCSP-24-1EP_4x4mm_P0.5mm_EP2.5x2.5mm_ThermalVias

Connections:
/3V3A: C233.1, C234.1, C235.1, U39.3 (+VS1), U39.4 (+VS1), U39.9 (+VS2), U39.10 (+VS2), U39.14 (~DISABLE2), U39.20 (~DISABLE1); also elsewhere on the board
/ADC1+: U39.13 (-OUT2); also elsewhere on the board
/ADC1-: U39.12 (+OUT2); also elsewhere on the board
/ADC2+: U39.18 (+OUT1); also elsewhere on the board
/ADC2-: U39.19 (-OUT1); also elsewhere on the board
/ADC_VCM1: C244.1, U39.17 (VOCM1); also elsewhere on the board
/ADC_VCM2: C245.1, U39.11 (VOCM2); also elsewhere on the board
/if/IF1+: C237.2, L11.1; also elsewhere on the board
/if/IF1-: C237.1, L10.1; also elsewhere on the board
/if/IF1a+: C239.2, C243.2, L11.2
/if/IF1a-: C239.1, C242.2, L10.2
/if/IF1b+: C243.1, R76.2
/if/IF1b-: C242.1, R75.2
/if/IF2+: C236.2, L9.1; also elsewhere on the board
/if/IF2-: C236.1, L8.1; also elsewhere on the board
/if/IF2a+: C238.2, C241.2, L9.2
/if/IF2a-: C238.1, C240.2, L8.2
/if/IF2b+: C241.1, R74.2
/if/IF2b-: C240.1, R73.2
GND: C233.2, C234.2, C235.2, C244.2, C245.2, U39.15 (-VS2), U39.16 (-VS2), U39.21 (-VS1), U39.22 (-VS1), U39.25 (EP); also elsewhere on the board
unnamed: C246.1, R78.1, U39.23 (-FB1)
unnamed: C246.2, R74.1, R78.2, U39.24 (+IN1)
unnamed: C247.1, R80.1, U39.5 (-FB2)
unnamed: C247.2, R76.1, R80.2, U39.6 (+IN2)
unnamed: C248.1, R73.1, R77.1, U39.1 (-IN1)
unnamed: C248.2, R77.2, U39.2 (+FB1)
unnamed: C249.1, R75.1, R79.1, U39.7 (-IN2)
unnamed: C249.2, R79.2, U39.8 (+FB2)

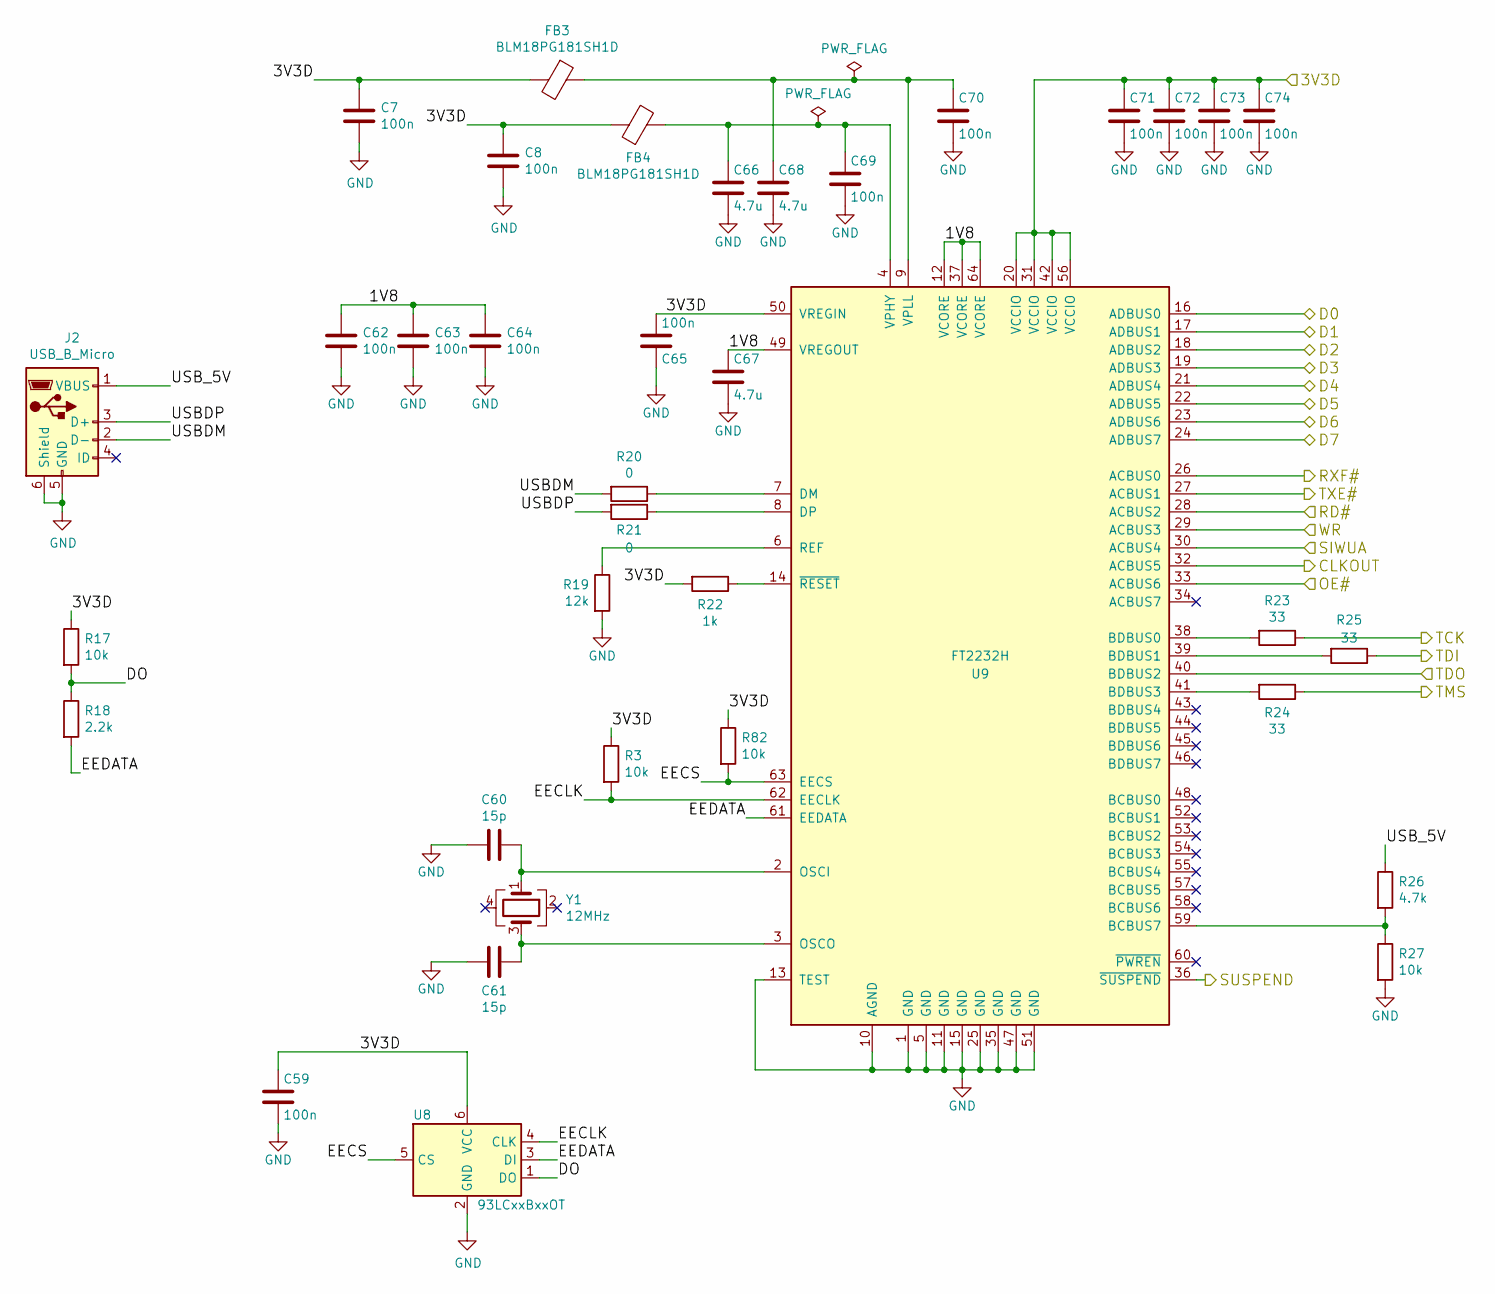
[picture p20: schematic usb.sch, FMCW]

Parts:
C7, C8, C59, C62, C63, C64, C65, C69, C70, C71, C72, C73, C74: 100n; C_0402_1005Metric
C60, C61: 15p; C_0402_1005Metric
C66, C67, C68: 4.7u; C_0603_1608Metric
FB3, FB4: BLM18PG181SH1D; L_0603_1608Metric
J2: USB_B_Micro; USB_Micro-B_Amphenol_10103594-0001LF_Horizontal
R3, R17, R27, R82: 10k; R_0402_1005Metric
R18: 2.2k; R_0402_1005Metric
R19: 12k; R_0402_1005Metric
R20, R21: 0; R_0402_1005Metric
R22: 1k; R_0402_1005Metric
R23, R24, R25: 33; R_0402_1005Metric
R26: 4.7k; R_0402_1005Metric
U8: 93LCxxBxxOT; SOT-23-6
U9: FT2232H; LQFP-64_10x10mm_P0.5mm
Y1: 12MHz; ABM10

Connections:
/3V3D: C7.1, C8.1, C59.1, C65.2, C71.1, C72.1, C73.1, C74.1, FB3.2, FB4.1, R3.1, R17.1, R22.2, R82.1, U8.6 (VCC), U9.20 (VCCIO), U9.31 (VCCIO), U9.42 (VCCIO), U9.50 (VREGIN), U9.56 (VCCIO); also elsewhere on the board
/fpga/CLKOUT: U9.32 (ACBUS5); also elsewhere on the board
/fpga/FT_D0: U9.16 (ADBUS0); also elsewhere on the board
/fpga/FT_D1: U9.17 (ADBUS1); also elsewhere on the board
/fpga/FT_D2: U9.18 (ADBUS2); also elsewhere on the board
/fpga/FT_D3: U9.19 (ADBUS3); also elsewhere on the board
/fpga/FT_D4: U9.21 (ADBUS4); also elsewhere on the board
/fpga/FT_D5: U9.22 (ADBUS5); also elsewhere on the board
/fpga/FT_D6: U9.23 (ADBUS6); also elsewhere on the board
/fpga/FT_D7: U9.24 (ADBUS7); also elsewhere on the board
/fpga/FT_SUSPEND: U9.36 (~SUSPEND); also elsewhere on the board
/fpga/OE#: U9.33 (ACBUS6); also elsewhere on the board
/fpga/RD#: U9.28 (ACBUS2); also elsewhere on the board
/fpga/RXF#: U9.26 (ACBUS0); also elsewhere on the board
/fpga/SIWUA: U9.30 (ACBUS4); also elsewhere on the board
/fpga/TCK: R23.1; also elsewhere on the board
/fpga/TDI: R25.1; also elsewhere on the board
/fpga/TDO: U9.40 (BDBUS2); also elsewhere on the board
/fpga/TMS: R24.1; also elsewhere on the board
/fpga/TXE#: U9.27 (ACBUS1); also elsewhere on the board
/fpga/WR: U9.29 (ACBUS3); also elsewhere on the board
/fpga/usb/1V8: C62.1, C63.1, C64.1, C67.1, U9.12 (VCORE), U9.37 (VCORE), U9.49 (VREGOUT), U9.64 (VCORE)
/fpga/usb/DO: R17.2, R18.1, U8.1 (DO)
/fpga/usb/EECLK: R3.2, U8.4 (CLK), U9.62 (EECLK)
/fpga/usb/EECS: R82.2, U8.5 (CS), U9.63 (EECS)
/fpga/usb/EEDATA: R18.2, U8.3 (DI), U9.61 (EEDATA)
/fpga/usb/USBDM: J2.2 (D-), R20.2
/fpga/usb/USBDP: J2.3 (D+), R21.2
/fpga/usb/USB_5V: J2.1 (VBUS), R26.1
GND: C7.2, C8.2, C59.2, C60.2, C61.2, C62.2, C63.2, C64.2, C65.1, C66.2, C67.2, C68.2, C69.2, C70.2, C71.2, C72.2, C73.2, C74.2, J2.5 (GND), J2.6 (Shield), R19.2, R27.2, U8.2 (GND), U9.1 (GND), U9.5 (GND), U9.10 (AGND), U9.11 (GND), U9.13 (TEST), U9.15 (GND), U9.25 (GND), U9.35 (GND), U9.47 (GND), U9.51 (GND); also elsewhere on the board
unnamed: C60.1, U9.2 (OSCI), Y1.1
unnamed: C61.1, U9.3 (OSCO), Y1.3
unnamed: C66.1, C69.1, FB4.2, U9.4 (VPHY)
unnamed: C68.1, C70.1, FB3.1, U9.9 (VPLL)
unnamed: R19.1, U9.6 (REF)
unnamed: R20.1, U9.7 (DM)
unnamed: R21.1, U9.8 (DP)
unnamed: R22.1, U9.14 (~RESET)
unnamed: R23.2, U9.38 (BDBUS0)
unnamed: R24.2, U9.41 (BDBUS3)
unnamed: R25.2, U9.39 (BDBUS1)
unnamed: R26.2, R27.1, U9.59 (BCBUS7)

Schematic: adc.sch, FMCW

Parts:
C75: 10u; C_0805_2012Metric
C76, C92, C93, C94: 2.2u; C_0603_1608Metric
C77, C84, C87, C88, C89, C90: 1u; C_0603_1608Metric
C78, C79, C80, C81, C82, C83: 100p; C_0402_1005Metric
C91, C95, C96, C97, C98, C99, C100, C101: 100n; C_0402_1005Metric
R28, R29, R30, R31: 49.9; R_0402_1005Metric
R32, R34, R35: 0; R_0402_1005Metric
R33: DNP; R_0402_1005Metric
R36: 22; R_0402_1005Metric
U10: LP5907MFX-3.0; SOT-23-5
U11: LTC2292; QFN-64-1EP_9x9mm_P0.5mm_EP7.15x7.15mm_ThermalVias

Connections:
/3V3D: C100.1, C101.1, U11.32 (OVDD), U11.49 (OVDD); also elsewhere on the board
/3V6: C75.1, U10.1 (IN), U10.3 (EN); also elsewhere on the board
/ADC1+: R31.2; also elsewhere on the board
/ADC1-: R29.2; also elsewhere on the board
/ADC2+: R30.2; also elsewhere on the board
/ADC2-: R28.2; also elsewhere on the board
/ADC_REF: R36.2, U11.8 (CLKA), U11.9 (CLKB); also elsewhere on the board
/ADC_VCM1: C92.2, U11.61 (VCMA); also elsewhere on the board
/ADC_VCM2: C76.1, U11.20 (VCMB); also elsewhere on the board
/fpga/ADC_OE1: U11.58 (~OEA); also elsewhere on the board
/fpga/ADC_OE2: U11.23 (~OEB); also elsewhere on the board
/fpga/ADC_SHDN1: U11.22 (SHDNB); also elsewhere on the board
/fpga/ADC_SHDN2: U11.59 (SHDNA); also elsewhere on the board
/fpga/D0: U11.43 (DA0); also elsewhere on the board
/fpga/D1: U11.44 (DA1); also elsewhere on the board
/fpga/D2: U11.45 (DA2); also elsewhere on the board
/fpga/D3: U11.46 (DA3); also elsewhere on the board
/fpga/D4: U11.47 (DA4); also elsewhere on the board
/fpga/D5: U11.48 (DA5); also elsewhere on the board
/fpga/D6: U11.51 (DA6); also elsewhere on the board
/fpga/D7: U11.52 (DA7); also elsewhere on the board
/fpga/D8: U11.53 (DA8); also elsewhere on the board
/fpga/D9: U11.54 (DA9); also elsewhere on the board
/fpga/D10: U11.55 (DA10); also elsewhere on the board
/fpga/D11: U11.56 (DA11); also elsewhere on the board
/fpga/OF1: U11.57 (OFA); also elsewhere on the board
/fpga/OF2: U11.40 (OFB); also elsewhere on the board
/fpga/adc/3V0: C77.1, C84.1, C91.1, C95.1, C98.1, C99.1, R32.1, R34.2, R35.2, U10.5 (OUT), U11.7 (VDD), U11.10 (VDD), U11.18 (VDD), U11.63 (VDD)
/fpga/adc/AINA+: C78.2, C79.1, R28.1, U11.1 (AINA+)
/fpga/adc/AINA-: C79.2, C80.1, R30.1, U11.2 (AINA-)
/fpga/adc/AINB+: C81.2, C82.1, R29.1, U11.16 (AINB+)
/fpga/adc/AINB-: C82.2, C83.1, R31.1, U11.15 (AINB-)
GND: C75.2, C76.2, C77.2, C78.1, C80.2, C81.1, C83.2, C84.2, C87.2, C88.2, C89.2, C90.2, C91.2, C92.1, C95.2, C98.2, C99.2, C100.2, C101.2, R33.2, U10.2 (GND), U11.17 (GND), U11.31 (OGND), U11.50 (OGND), U11.64 (GND), U11.65 (GND); also elsewhere on the board
unnamed: C87.1, C93.1, C96.1, U11.3 (REFHA), U11.4 (REFHA)
unnamed: C88.1, C93.2, C96.2, U11.5 (REFLA), U11.6 (REFLA)
unnamed: C89.1, C94.1, C97.1, U11.13 (REFHB), U11.14 (REFHB)
unnamed: C90.1, C94.2, C97.2, U11.11 (REFLB), U11.12 (REFLB)
unnamed: R32.2, R33.1, U11.60 (MODE)
unnamed: R34.1, U11.62 (SENSEA)
unnamed: R35.1, U11.19 (SENSEB)
unnamed: R36.1, U11.21 (MUX)

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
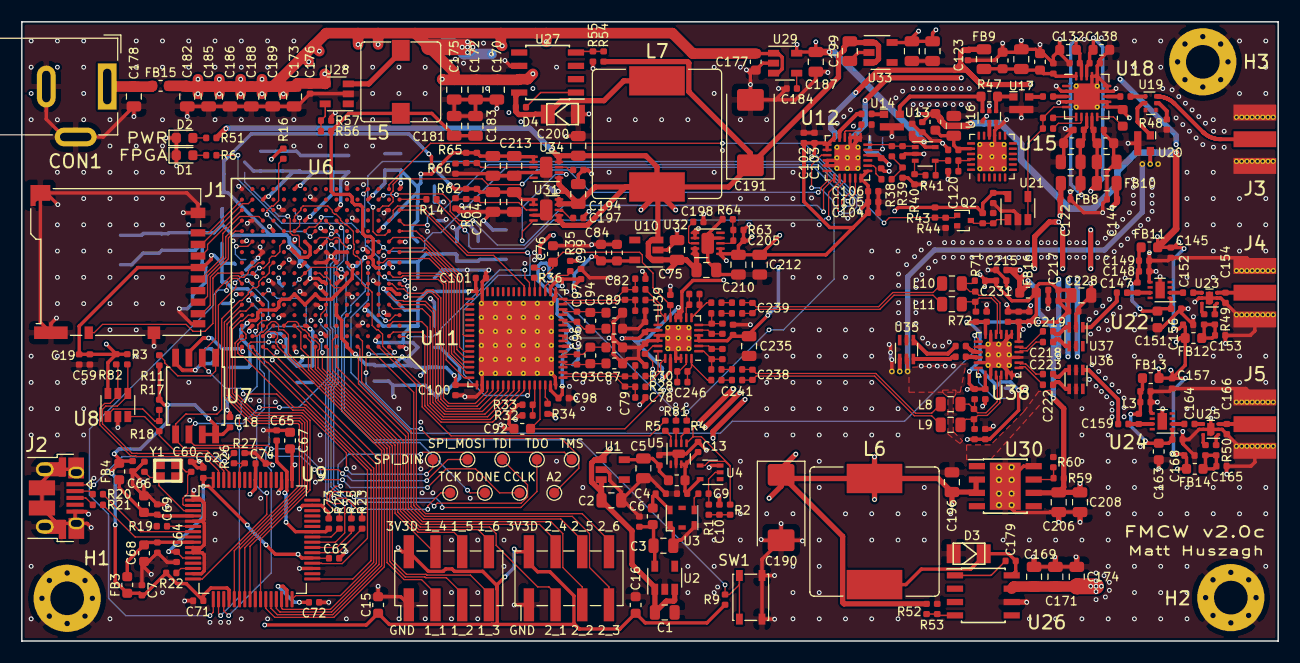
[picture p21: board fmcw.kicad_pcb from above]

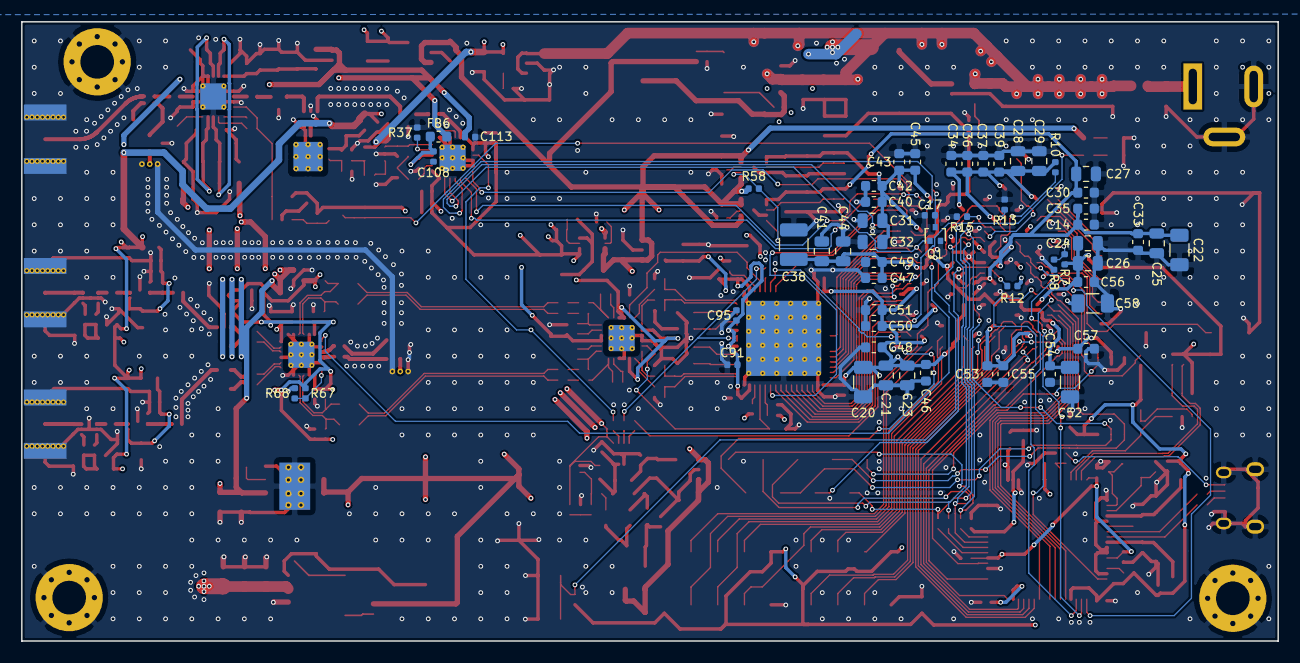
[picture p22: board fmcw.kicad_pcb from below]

Board: 4 copper layers, 119.6 x 58.9 mm, 415 parts (57 on the bottom side), 247 nets.

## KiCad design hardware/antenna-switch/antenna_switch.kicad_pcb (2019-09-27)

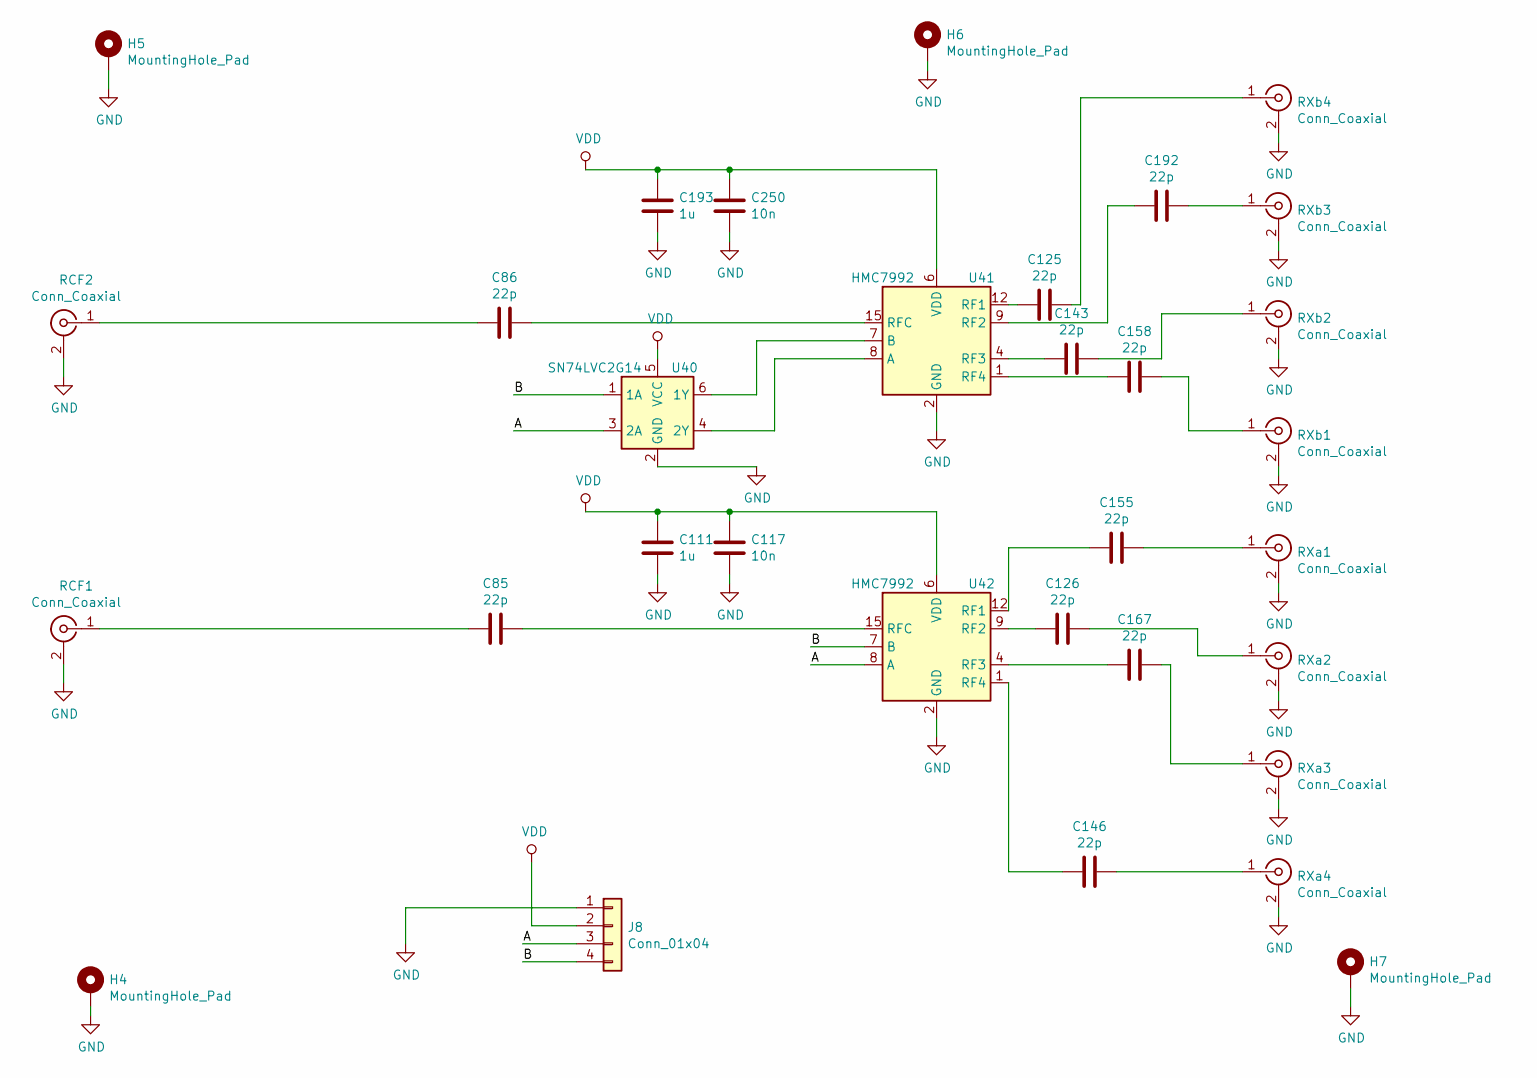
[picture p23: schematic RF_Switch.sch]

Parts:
C85, C86, C125, C126, C143, C146, C155, C158, C167, C192: 22p; C_0402_1005Metric
C111, C193: 1u; C_0603_1608Metric
C117, C250: 10n; C_0402_1005Metric
H4, H5, H6, H7: MountingHole_Pad; MountingHole_2.5mm_Pad_Via
J8: Conn_01x04; PinHeader_1x04_P2.54mm_Vertical
RCF1, RCF2: Conn_Coaxial; CONSMA003.062
RXa1, RXa2, RXa3, RXa4: Conn_Coaxial; CONSMA003.062
RXb1, RXb2, RXb3, RXb4: Conn_Coaxial; CONSMA003.062
U40: SN74LVC2G14; SOT-23-6
U41, U42: HMC7992; LFCSP-16-1EP_3x3mm_P0.5mm_EP1.7x1.7mm

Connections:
/RF Switch/A: J8.3, U40.3 (2A), U42.8 (A)
/RF Switch/B: J8.4, U40.1 (1A), U42.7 (B)
GND: C111.1, C117.1, C193.1, C250.1, H4.1, H5.1, H6.1, H7.1, J8.1, RCF1.2 (Ext), RCF2.2 (Ext), RXa1.2 (Ext), RXa2.2 (Ext), RXa3.2 (Ext), RXa4.2 (Ext), RXb1.2 (Ext), RXb2.2 (Ext), RXb3.2 (Ext), RXb4.2 (Ext), U40.2 (GND), U41.2 (GND), U41.3 (GND), U41.5 (GND), U41.10 (GND), U41.11 (GND), U41.13 (GND), U41.14 (GND), U41.16 (GND), U41.17 (GND), U42.2 (GND), U42.3 (GND), U42.5 (GND), U42.10 (GND), U42.11 (GND), U42.13 (GND), U42.14 (GND), U42.16 (GND), U42.17 (GND)
unnamed: C85.1, U42.15 (RFC)
unnamed: C85.2, RCF1.1 (In)
unnamed: C86.1, U41.15 (RFC)
unnamed: C86.2, RCF2.1 (In)
unnamed: C125.1, RXb4.1 (In)
unnamed: C125.2, U41.12 (RF1)
unnamed: C126.1, RXa2.1 (In)
unnamed: C126.2, U42.9 (RF2)
unnamed: C143.1, RXb2.1 (In)
unnamed: C143.2, U41.4 (RF3)
unnamed: C146.1, RXa4.1 (In)
unnamed: C146.2, U42.1 (RF4)
unnamed: C155.1, RXa1.1 (In)
unnamed: C155.2, U42.12 (RF1)
unnamed: C158.1, RXb1.1 (In)
unnamed: C158.2, U41.1 (RF4)
unnamed: C167.1, RXa3.1 (In)
unnamed: C167.2, U42.4 (RF3)
unnamed: C192.1, RXb3.1 (In)
unnamed: C192.2, U41.9 (RF2)
unnamed: U40.4 (2Y), U41.8 (A)
unnamed: U40.6 (1Y), U41.7 (B)
VDD: C111.2, C117.2, C193.2, C250.2, J8.2, U40.5 (VCC), U41.6 (VDD), U42.6 (VDD)



Board: 4 copper layers, 45.2 x 53.3 mm, 32 parts (14 on the bottom side), 26 nets.

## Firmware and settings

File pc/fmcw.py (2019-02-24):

#!/usr/bin/python

import pylibftdi as ftdi
from adf4158 import ADF4158
from queue import Queue, Empty
from threading import Thread
import datetime
import keyboard
import os


class FMCW():
    """Interface to the FMCW radar."""

    def __init__(self):
        SYNCFF = 0x40  # Configures bit-bang mode for synchronous FIFO.
        SIO_RTS_CTS_HS = (0x1 << 8)
        self.device = ftdi.Device(mode='t', interface_select=ftdi.INTERFACE_A)
        self.device.open()
        self.device.ftdi_fn.ftdi_set_bitmode(0xff, SYNCFF)
        self.device.ftdi_fn.ftdi_read_data_set_chunksize(0x10000)
        self.device.ftdi_fn.ftdi_write_data_set_chunksize(0x10000)
        self.device.ftdi_fn.ftdi_setflowctrl(SIO_RTS_CTS_HS)
        self.device.flush()

        self.pll = ADF4158()
        self.fclk = 40e6
        self.fpd_freq = self.fclk/2

    def close(self):
        self.device.close()
        return

    def send_packet(self, x, cmd):
        try:
            l = len(x)
        except TypeError:
            l = 1
            x = [x]

        header = [0xaa, l, cmd]
        b = bytearray(header+x)
        # print map(hex, map(ord, str(b)))
        return self.device.write(b)

    def clear_gpio(self, led=False, pa_off=False, mix_enbl=False, adf_ce=False):
        w = 0
        if led:
            w |= 1 << 0
        if pa_off:
            w |= 1 << 1
        if mix_enbl:
            w |= 1 << 2
        if adf_ce:
            w |= 1 << 3
        return self.send_packet(w, 0)

    def set_gpio(self, led=False, pa_off=False, mix_enbl=False, adf_ce=False):
        w = 0
        if led:
            w |= 1 << 0
        if pa_off:
            w |= 1 << 1
        if mix_enbl:
            w |= 1 << 2
        if adf_ce:
            w |= 1 << 3
        return self.send_packet(w, 1)

    def clear_adc(self, oe1=False, oe2=False, shdn1=False, shdn2=False):
        w = 0
        if oe1:
            w |= 1 << 0
        if oe2:
            w |= 1 << 1
        if shdn1:
            w |= 1 << 2
        if shdn2:
            w |= 1 << 3
        return self.send_packet(w, 2)

    def set_adc(self, oe1=False, oe2=False, shdn1=False, shdn2=False):
        w = 0
        if oe1:
            w |= 1 << 0
        if oe2:
            w |= 1 << 1
        if shdn1:
            w |= 1 << 2
        if shdn2:
            w |= 1 << 3
        return self.send_packet(w, 3)

    def write_pll_reg(self, n):
        reg = self.pll.registers[n]
        w = [(reg & 0xff) | n, (reg >> 8) & 0xff,
             (reg >> 16) & 0xff, (reg >> 24) & 0xff]
        return self.send_packet(w, 4)

    def write_pll(self):
        self.write_pll_reg(7)
        self.pll.write_value(step_sel=0)
        self.write_pll_reg(6)
        self.pll.write_value(step_sel=1)
        self.write_pll_reg(6)
        self.pll.write_value(dev_sel=0)
        self.write_pll_reg(5)
        self.pll.write_value(dev_sel=1)
        self.write_pll_reg(5)
        for i in range(4, -1, -1):
            self.write_pll_reg(i)

    def set_sweep(self, fstart, bw, length, delay):
        real_delay = self.pll.freq_to_regs(
            fstart, self.fpd_freq, bw, length, delay)
        self.write_pll()
        return real_delay

    def write_sweep_timer(self, length):
        length = int(self.fclk*length)
        w = [(length & 0xff), (length >> 8) & 0xff,
             (length >> 16) & 0xff, (length >> 24) & 0xff]
        return self.send_packet(w, 5)

    def write_sweep_delay(self, length):
        length = int(self.fclk*length)
        w = [(length & 0xff), (length >> 8) & 0xff,
             (length >> 16) & 0xff, (length >> 24) & 0xff]
        return self.send_packet(w, 6)

    def set_channels(self, a=True, b=True):
        w = 0
        if a:
            w |= 1 << 0
        if b:
            w |= 1 << 1
        return self.send_packet(w, 7)

    def set_downsampler(self, enable=True, quarter=False):
        w = 0
        if enable:
            w |= 1 << 0
        if quarter:
            w |= 1 << 1
        return self.send_packet(w, 8)

    def write_decimate(self, decimate):
        if decimate > 2**16-1 or decimate < 1:
            raise ValueError("Invalid decimate value")
        decimate = int(decimate) - 1
        w = [decimate & 0xff, (decimate >> 8) & 0xff]
        return self.send_packet(w, 9)

    def write_pa_off_timer(self, length):
        length = int(self.fclk*length)
        w = [(length & 0xff), (length >> 8) & 0xff,
             (length >> 16) & 0xff, (length >> 24) & 0xff]
        return self.send_packet(w, 10)

    def clear_buffer(self):
        return self.send_packet(0, 11)


class Writer(Thread):
    def __init__(self, filename, queue):
        Thread.__init__(self)
        self.queue = queue
        self.f = open(filename, 'w')

    def run(self):
        wrote = 0
        while True:
            try:
                d = self.queue.get(True, 0.5)
            except Empty:
                print('Timeout', wrote)
                self.f.close()
                return
            if len(d) == 0:
                print('Closed', wrote)
                self.f.close()
                return
            else:
                self.f.write(d)
                wrote += len(d)


if __name__ == '__main__':
    if os.getuid() != 0:
        raise PermissionError(
            "Must be run with superuser privileges.")

    fmcw = FMCW()

    f0 = 5.3e9
    bw = 600e6
    tsweep = 1e-3
    tdelay = 2e-3
    pa_off_advance = 0.2e-3
    decimate = 3
    ch_a = True
    ch_b = True
    downsampler = True
    quarter = False

    fmcw.set_gpio(led=True, adf_ce=True)
    fmcw.set_adc(oe2=True)
    fmcw.clear_adc(oe1=True, shdn1=True, shdn2=True)
    delay = fmcw.set_sweep(f0, bw, tsweep, tdelay)

    fmcw.set_downsampler(enable=downsampler, quarter=quarter)
    fmcw.write_sweep_timer(tsweep)
    fmcw.write_sweep_delay(tdelay)
    fmcw.write_decimate(decimate)
    fmcw.write_pa_off_timer(tdelay - pa_off_advance)
    fmcw.clear_gpio(pa_off=True)
    fmcw.clear_buffer()

    q = Queue()

    date = datetime.datetime.now().strftime("%Y-%m-%d %H:%M:%S")

    settings_dict = {'date': date, 'f0': f0, 'bw': bw, 'tsweep': tsweep, 'tdelay': tdelay,
                     'a': ch_a, 'b': ch_b, 'decimate': decimate, 'downsampler': downsampler, 'quarter': quarter}

    settings = 'fmcw; {}'.format(settings_dict)

    ls = len(settings)
    len_settings = ''.join(map(chr, [ls & 0xff, (ls >> 8) & 0xff]))

    settings = len_settings+settings

    q.put(settings)

    writer = Writer('fmcw.log', q)
    writer.start()

    fmcw.set_channels(a=ch_a, b=ch_b)

    try:
        print("Type 'q' to finish reading data.")
        while True:
            r = fmcw.device.read(0x10000)
            if len(r) != 0:
                q.put(r)
            if keyboard.is_pressed('q'):
                break

    finally:
        fmcw.set_adc(oe1=True, shdn1=True, shdn2=True)
        fmcw.set_channels(a=False, b=False)
        fmcw.clear_gpio(led=True, adf_ce=True)
        fmcw.set_gpio(pa_off=True)
        fmcw.clear_buffer()
        fmcw.close()
        print('Done')
        q.put('')
        writer.join()

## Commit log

2017-09-27 Fix FPGA programming resistor connections
    M[2:0] were wired incorrectly when I ordered the board. For programming from SPI
    memory M[2:0] should be "001", but I had them wired backwards as "100". I fixed
    it with one jump wire, but here is a proper fix for anyone looking to reproduce
    the design.
    [fmcw3.kicad_pcb, fpga.sch]
2018-10-06 Current working version.
    [adc.sch, fmcw3.csv, fmcw3.kicad_pcb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]
2018-10-10 Dropped the 3 from the end of the project name.
    [adc.sch, fmcw.kicad_pcb, fmcw.sch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]
2018-12-11 Modularized LaTeX documentation.
    [adc.sch, fmcw.kicad_pcb, fmcw.sch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]
2018-12-18 Adjusted power supply for new power amplifier.
    [adc.sch, fmcw.sch, fpga.sch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]
2018-12-20 Documentation for TPS5420D buck converter.
    [adc.sch, fmcw.kicad_pcb, fmcw.sch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]
2018-12-26 Made some modifications to the power hardware.
    [mixer.sch, power.sch]
2018-12-30 Improved top level documentation.
    [adc.sch, fmcw.sch, if.sch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]
2019-01-04 Added MFNs to components.
    [adc.sch, fmcw.kicad_pcb, fmcw.sch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]
2019-01-04 Fixed ERC errors.
    [fmcw.kicad_pcb, fmcw.sch, fpga.sch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]
2019-01-08 Improved documentation and added schematics to default libraries.
    [adc.sch, fmcw.sch, fpga.sch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]
2019-01-08 Improved tx sheet and corresponding documentation.
    [fpga.sch, if.sch, mixer.sch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]
2019-01-09 Improved documentation and parts of the schematic.
    [adc.sch, fmcw.sch, fpga.sch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]
2019-01-11 Changed components to official libs.
    [adc.sch, fmcw.sch, fpga.sch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]
2019-01-12 Finished design, began routing.
    [adc.sch, fmcw.kicad_pcb, fmcw.sch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]
2019-01-13 Placed most major components.
    [fmcw.kicad_pcb, fmcw.sch, rx.sch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]
2019-01-14 Completed clock placement and routing.
    [adc.sch, fmcw.kicad_pcb, fmcw.sch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]
2019-01-15 Place/route for ft2232h.
    [adc.sch, fmcw.kicad_pcb, fmcw.sch]
2019-01-15 Fixed transmission line width.
    [fmcw.kicad_pcb, fmcw.sch, if.sch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]
2019-01-15 Added test points.
    [fmcw.kicad_pcb]
2019-01-16 Completed FPGA bypassing.
    [fmcw.kicad_pcb, fpga.sch, mixer.sch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]
2019-01-16 Placed/routed all FPGA external components.
    [fmcw.kicad_pcb]
2019-01-16 Better MFNs for RF DC blocking caps.
    [adc.sch, fmcw.kicad_pcb, if.sch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]
2019-01-16 Completed transmitter placement/routing.
    [fmcw.kicad_pcb, mixer.sch, rx.sch]
2019-01-17 Completed receivers.
    [adc.sch, fmcw.kicad_pcb, mixer.sch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]
2019-01-17 Finished placing.
    [fmcw.kicad_pcb]
2019-01-17 Passes DRC.
    [fmcw.kicad_pcb, tx.sch]
2019-01-17 Completed power plane.
    [fmcw.kicad_pcb]
2019-01-17 Replaced relevant footprints for thermal via variety.
    [adc.sch, fmcw.kicad_pcb, if.sch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]
2019-01-18 Improved silkscreen appearance.
    [fmcw.kicad_pcb, fpga.sch]
2019-01-23 Documentation changes.
    [adc.sch, fmcw.kicad_pcb, fmcw.sch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]
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2019-01-24 Documentation improvements and spice simulations.
    [if-filter.sch]
2019-02-02 Filter FPGA code.
    [patch_1x5-B.Cu.gbl, patch_1x5-B.Mask.gbs, patch_1x5-B.SilkS.gbo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]
2019-02-02 Place ADC logic directly in top level module.
2019-02-10 Finish FPGA code.
    [adc.sch, fmcw.kicad_pcb, fmcw.sch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]
2019-02-24 Added Makefiles to facilitate running code. Reorganized code.
    [interface.cfg, program_flash.cfg, program_fpga.cfg]
2019-02-24 Add buffer amp for power amp reference voltage.
    [adc.sch, fmcw.kicad_pcb, fmcw.sch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]
2019-02-27 Improve PCB.
    [adc.sch, fmcw.kicad_pcb, fmcw.sch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]
2019-02-28 Add RF antenna switch.
    [RF_Switch.sch, adc.sch, antenna_switch.kicad_pcb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]
2019-08-10 Unoptimized, working FFT
    This commit is a huge abuse of git, I know...
    [adc.sch, fmcw.kicad_pcb, fmcw.sch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]
2019-09-27 Huge, messy commit before I begin replacing FPGA code
    [RF_Switch.sch, antenna_switch.kicad_pcb, antenna_switch.sch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]
2019-10-04 Add linker flags to Makefile for reading bytes from fmcw board
2019-10-05 Fix FFT power computation when reading bytes
2019-10-06 Replace adc.v with ltc2292.v
    This uses a dedicated libdigital interface in
    place of the old adc.v interface.
2019-10-16 Remove adc module from makefile
2019-10-16 Only enable mixer and power amplifier when in use
2019-10-16 Current plotting and reading implementation
2019-10-16 Only enable ADC when in use
2019-11-05 reorganize project and create synthesizable top level
    [interface.cfg, program_flash.cfg, program_fpga.cfg]
2019-11-08 top verilog: replace ram with fifo
    Between filter and fft
2019-11-14 better control logic
    The FPGA control logic is now more tightly
    regulated so we don't process data between
    frequency ramps, for instance. This is all placed
    in a dedicated module.
    [plot.py]
2019-11-17 interact with radar as normal user
    This requires proper udev setup but is useful
    since it allows interaction with the board as a
    normal user. One example where this comes in handy
    is when debugging the code to read from the radar.
2019-11-21 generalize top-level control logic
    This makes it easier to switch between sending
    fully-processed data and data in some intermediate
    state.
2019-11-22 move spice sims
    [if-filter.sch]
2019-12-06 software: add interpolation and thread for user input
2019-12-11 software: communicate with python as subprocess
    This is a major overhaul of the previous PC code configuration. There
    are 2 major changes:
    1. Allow any breakdown of processing between PC and FPGA. The PC can
    also optionally skip steps (the FPGA currently cannot).
    2. Communicate with the Python plotting code as a subprocess of the C
    code. The python process is started as an unnamed pipe and data is
    sent to it via stdin. Data is no longer written to the filesystem,
    although this might be added as an additional option for debugging
    purposes.
    [plot.py]
2019-12-11 software: fix FFT hist plotting and other bug fixes
    [plot.py]
2019-12-12 gateware: fix window module
    [plot.py]
2019-12-12 gateware: move source files
    [interface.cfg, program_flash.cfg, program_fpga.cfg]
2019-12-19 cad: add antenna mount
    [antenna-mount.scad]
2019-12-19 gateware: sync led with power amplifier
    Data is transmitted too infrequently to the PC to be visible via the
    LED.
2020-01-03 pcb: connect ADC reference to voltage supply rail
    [adc.sch, fmcw.kicad_pcb, fmcw.sch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]
2020-01-23 doc: add fir filter high-level description
2020-01-23 doc: clarify 1MHz cutoff for FIR filter
2020-01-28 doc: add FFT schematic
2020-01-31 doc: minimum detectable power and max range
2020-02-02 doc: adc high-level description
2020-02-02 doc: add note about omitted adc 2nd channel
2020-02-03 remove old gateware
    [interface.cfg, program_flash.cfg, program_fpga.cfg]
2020-02-03 move main pcb hardware to boards+version subdirectory
    [adc.sch, fmcw.kicad_pcb, fmcw.sch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]
2020-02-21 add horn antenna openems simulation
2020-02-24 fix fir bug related to improper normalization factor
    [fir.py, plot.py]
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
